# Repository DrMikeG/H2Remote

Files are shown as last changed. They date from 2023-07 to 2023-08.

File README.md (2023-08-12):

# H2Remote

## 12th August 2023 ##

Back to the Tiny

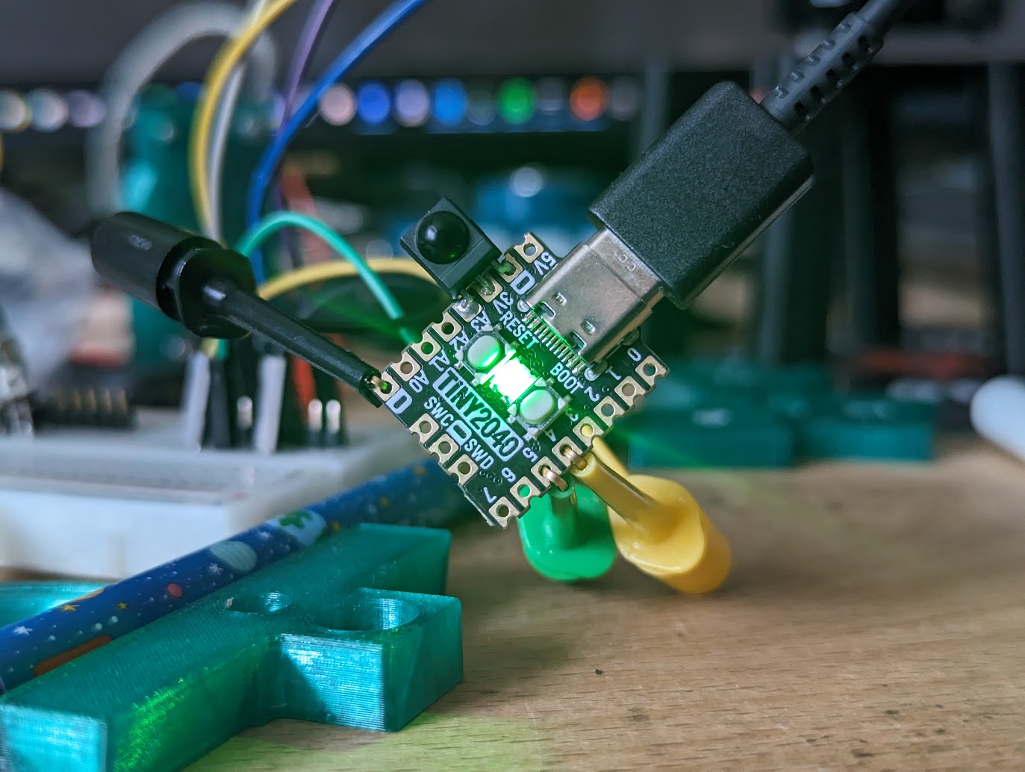
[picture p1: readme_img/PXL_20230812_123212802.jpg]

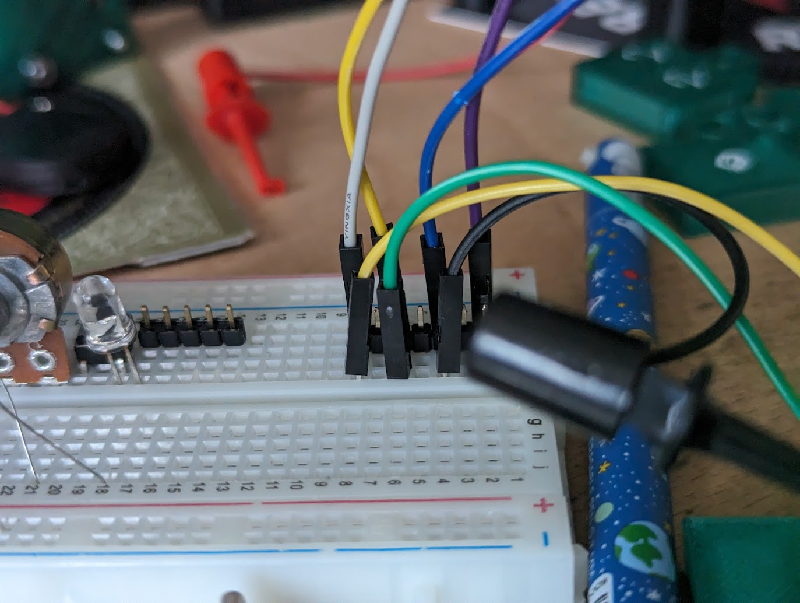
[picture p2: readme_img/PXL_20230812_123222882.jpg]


With minor revisions changing from the NeoPixel to the RGB LED, the code from the feather works on the Tiny.
The hardware UART RX/TX are GP4 and GP5.

blue wire in cable L - GP5 (green clip) connects to the yellow lead, which is L on 2.5mm jack
green wire in cable R - GP4 (yellow clip) connects to the white lead, which is R on 2.5mm jack
copper wire in cable (GND) - GND pin on Tiny
red wire (3v3) cut short

## 5th August 2023 ##

Today I got the feather 2040 flashing its neo pixel.
I also got it to read from the IR receiver.

I tried to decode the remote protocol - thinking it would encode an RGB value - but I'm pretty sure it's just sending an int for each remote key, and the device is mapping the int to a specific color or behaviour.

Looking at the pin order on the feature, it was actually better to swap back to a vs1838b IR receiver, as the pinout is the compatible (although backwards) with 3v3/GND/A0 on the feather.

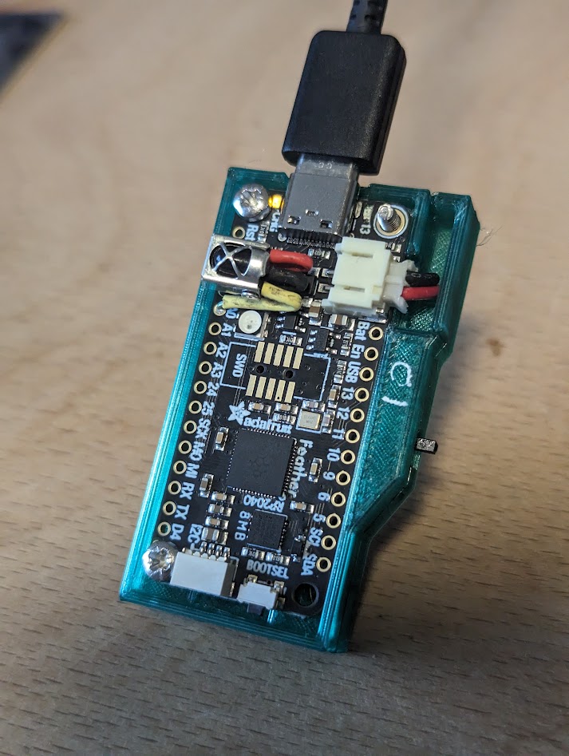
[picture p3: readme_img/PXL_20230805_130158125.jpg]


I also connected the lipo battery (via the switch) which is now being charged (small yellow LED top left)

Next step is to review the TX/RX with the zoom and figure out a common gnd.

On the Pico - I had success with 
``uart2 = busio.UART(board.GP4, board.GP5, baudrate=2400, bits=8, parity=None, stop=1)``





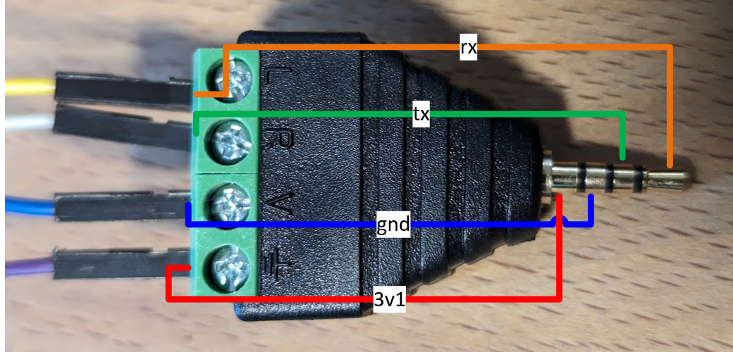
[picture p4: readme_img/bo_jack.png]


UART1 TX and UART1 RX

From the feather documentation:

>>> CircuitPython I2C, SPI and UART
Note that in CircuitPython, there is a board object each for I2C, SPI and UART that use the pins labeled on the Feather. You can use these objects to initialise these peripherals in your code.
```
board.STEMMA_I2C() uses SCL/SDA
board.SPI() uses SCK/MO/MI
board.UART() uses RX/TX
```

```
UART Pins:
UART0 TX: TX, A2, D12
UART0 RX: RX, A3, D13

UART1 TX: D24, MISO, D6
UART1 RX: D25, D9
```

Using the feather I can successfully communicate with the H2 to start and stop recording.
I had 24/25 backwards for a while - and listening seemed to work.

pin 25 is connected to L on the 2.5mm terminal block
pin 24 is connected to R on the 2.5mm terminal block
pin 10 (pseudo gnd) is connected to V on the 2.5mm terminal block

## 4th August 2023 ##

This evening was my first opportunity to start working with the feather 2040

Firstly, I've solvered up some sprung-clip test leads onto some du pont male breadboard leads.

This allows me to make secure connections to the board without soldering on headers.
Very pleased with that idea.

The feature has a very different list of pins available compare to the pico.
I took the 01_pico_IR example and edited it into 08_feather_IR - editing the default pin from GP22 to D6 and editing the pin in use too.
This was the only modification necessary though.

## 31st July 2023 ##

So, I made a boo boo.
The port on the H2 is current limited to 10mA, and despite my previous readings, the tiny 2040 need 25mA to run.
This isn't a surprise as the 2040 chip needs 20mA to idle.

I can't think of a way around this limit, so my board is going to need external power.
I considered some coin cell batteries, and I might go there, but first I want to try a lipo battery.
I went looking for a charging shim with an on/off switch, but realised that most more larger than the tiny 2040, and would present more
mounting problems.

Since I have lost my size advantage, I have ordered a different board to work with, one with native lipo support.
I considered the pimironi version of this, which has an on/off button, but decided I'm going to want the on/off broken out to the side of the case anyway.

https://learn.adafruit.com/adafruit-feather-rp2040-pico/pinouts
https://io.adafruit.com/blog/tip/2016/12/14/feather-power-switch/
https://learn.adafruit.com/adafruit-feather-m0-basic-proto/power-management#enable-pin

## 23rd July 2023 ##
Another thread to pick at:
https://github.com/radicalrendell/zoom_remote/blob/master/zoomctl.py

https://www.webwork.co.uk/2021/03/wireless-remote-control-for-zoom-h2n.html
https://github.com/lowfriars/ZoomRemote

With Zoom connected with trrs breakout, L (yellow wire) on the breakout connects to ping GP4 on a pico.
Code in 04_pico_zoom_rx can receive bits
0x81,0x80

In some of example code for a zoom H4 remote, there is a handshake

```
# handshake
# return true if connected, false if not
def zhandshake(s):
    # send 00, look for 80, then send A1, look for 80 then we are ready
    s.write('\x00')

    zbyte = s.read(1)
    if (zbyte == '\x80'): s.write('\xa1')
        
    zbyte = s.read(1)
    if (zbyte == '\x80'): return(1) 
    return(0)
```

I don't know if sending A1 would do anything for the H2, because we seem to receive an alternating stream of 80,81,80 as it is.

>> Although the recorder supplies 3.3V power, it's not capable of supplying much current, certainly not enough for a wireless link, so regrettably the wireless interface needs its own power source. The communication protocol was clearly designed by an electrical engineer: it consists of key-down and key-up events being sent to the recorder to signal the press and release of buttons on the physical remote control and an encoded status byte being sent to the remote control to illuminate status LEDs (such as recording-in-progress and level indicators). There is an initial handshake to establish the connection of the remote control. 

https://www.webwork.co.uk/2021/05/wireless-remote-control-for-zoom-h2n.html

>>  The control protocol calls for a code to be sent when a button is pressed and a further code when it is released (this allows, for example, auto-repeat on the Volume controls). The codes corresponding to the "press" event for each button are stored in the keySequence dictionary (the release code is the same for all keys).

Data received from the H2n consists of a singled byte which is encoded as follows (red and green refer to VU meter, both on together corresponds to yellow):

Initially, the Zoom device sends a sequence of two bytes: for the H2n these are 0x80 and 0x81, for other devices they may be 
different, but the high bit of 0x80 appears to be intended to signify that it's a two-byte sequence. 

The service sends "key up" messages to the recorder. 

At some point, the recorder recognises the existence of the remote controller and switches to one-byte
responses with the top bit clear. The contents of each byte represents the status of the recorder as follows:
/// 
/// Bit 7   -   1 for handshake phase, 0 once remote control has been acknowledged
/// Bit 6   -   Green status for recorder channel 3
/// Bit 5   -   Green status for recorder channel 1
/// Bit 4   -   Greet status for recorder channel 2
/// Bit 3   -   Red status for recorder channel 3
/// Bit 2   -   Red status for recorder channel 1
/// Bit 1   -   Red status for recorder channel 2
/// Bit 0   -   1 if recording in progress (alternates 0 and 1 when recording paused)

I think the button up code is:
s.write('\x80\x00')

Gradually building up from the various great bits of example code, I've managed to:
- read the h2 RX line
- 'handshake' with the h2 on its TX line
- interpret the post-handshake byte on the h2 RX line
- Send start/stop record in the TX line

This is currently being done with the UART pins, not with PIO.

I need to understand more about PIO if I want to avoid needing to use UART.

I struggled to get two example running at once, so I'm going to try and build a new example with flashing an LED and reading the IR diode.

https://learn.adafruit.com/intro-to-rp2040-pio-with-circuitpython/using-pio-to-blink-a-led-quickly-or-slowly

## 22nd July 2023 ##

Serial 2400 8b no parity 1 stop (8n1)
Bit order: LSB first, inverted logic: no
https://github.com/raspberrypi/pico-examples/blob/master/pio/uart_rx/uart_rx.pio

"With no activity on the recorder the RX and TX pins show ~2.7 volts"

"When you press the record button on the remote, after a moment the recording LED lights up"

"On the oscilloscope I can see three different square wave patterns for the three different buttons on the TX pin and a single type of square wave
on RX to light the LED."

"The following images show the signal for the record button then that sent in
response to to light the LED.

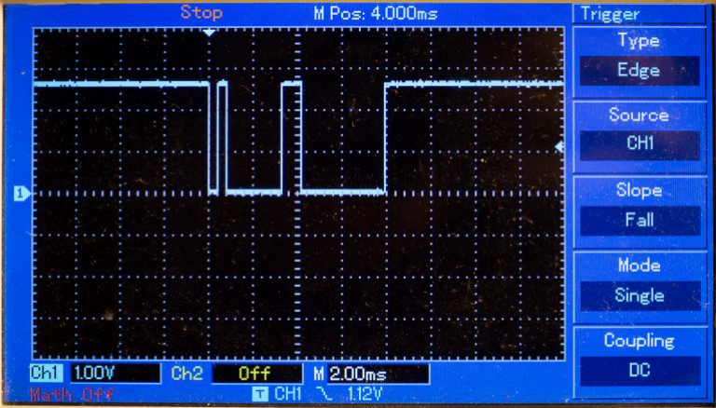
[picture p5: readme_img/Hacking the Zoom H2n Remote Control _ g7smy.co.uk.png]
Signal sent by the remote when Record pressed
 Signal sent by the remote when Record pressed

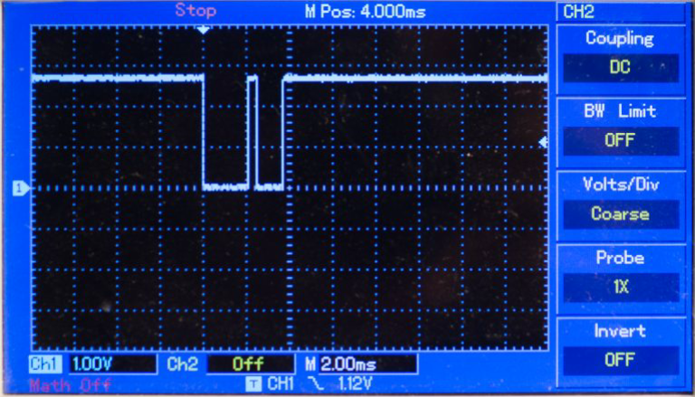
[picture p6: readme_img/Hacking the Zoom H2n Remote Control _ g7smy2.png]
Signal sent by the Zoom recorder to light the LED in the remote
 Signal sent by the Zoom recorder to light the LED in the remote

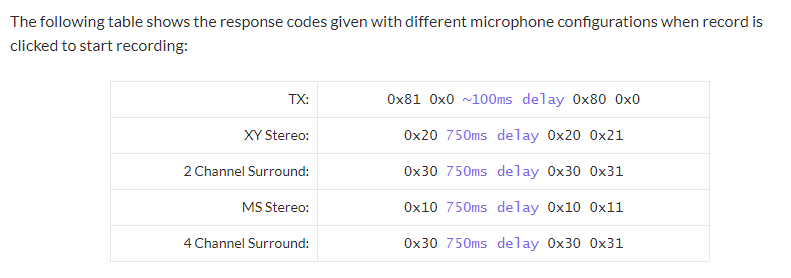
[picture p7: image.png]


Can I get the first byte of the response? 0x20

Using teensy example code:
```
// incoming data
Serial2.begin(2400, SERIAL_8N1);  // Remote Receive - RX
Serial3.begin(2400, SERIAL_8N1);  // Remote Transmit - TX
```

https://arduino-pico.readthedocs.io/en/latest/piouart.html

```
Equivalent to the Arduino SoftwareSerial library, an emulated UART using one or two PIO state machines is included in the Arduino-Pico core. This allows for up to 4 bidirectional or up to 8 unidirectional serial ports to be run from the RP2040 without requiring additional CPU resources.

Instantiate a SerialPIO(txpin, rxpin, fifosize) object in your sketch and then use it the same as any other serial port. Even, odd, and no parity modes are supported, as well as data sizes from 5- to 8-bits. Fifosize, if not specified, defaults to 32 bytes.
```

https://learn.adafruit.com/intro-to-rp2040-pio-with-circuitpython?view=all

## 21st July 2023 ##

My TSOP2238 IR diodes arrived today.
These have a different leg ordering to the standard pins I use.

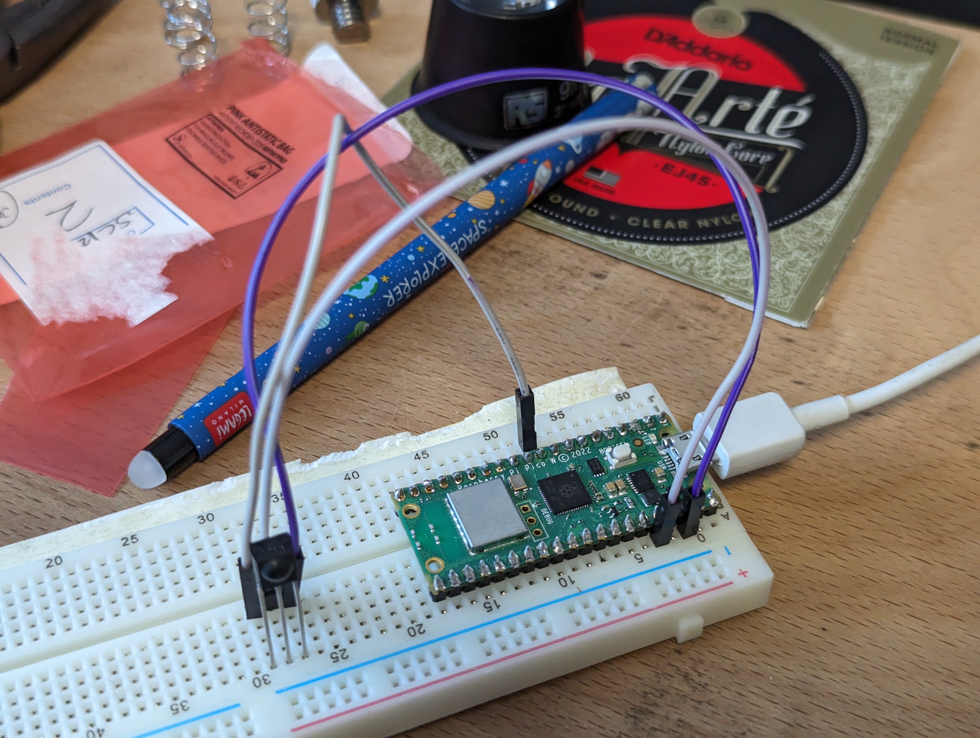
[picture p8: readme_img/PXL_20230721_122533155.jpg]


Pin 1 (left when facing) - purple wire to GND
Pin 2 - white wire to 3v3
Pin 3 grey wire to GP07 (working with test script 01_pico_IR_PIO)

This works great, so I can plan to solder it on to the Tiny_2040

## 18th July 2023 ##

Serial 2400 8b no parity 1 stop (8n1)
Bit order: LSB first, inverted logic: no
https://github.com/raspberrypi/pico-examples/blob/master/pio/uart_rx/uart_rx.pio

// bytes to start and stop the recorder, a negative number is used as a delay
int record[5] = { 0x81, 0x0, -100, 0x80, 0x0 };  

# 17th July 2023 ##

Tiny 2040 from Pimoroni is compatible with firmware designed for the Raspberry Pi Pico.

It is one-third of the size of a Raspberry Pi Pico & has 16 GPIO pins while Raspberry Pi Pico has 40 pins.

With proper orientations & mapping of the pins, there is no loss of functionality despite lesser pins.

Board has some unique features that Raspberry Pi Pico does not have, such as a dedicated reset button, a fourth ADC pin, RGB LED & USB C port.

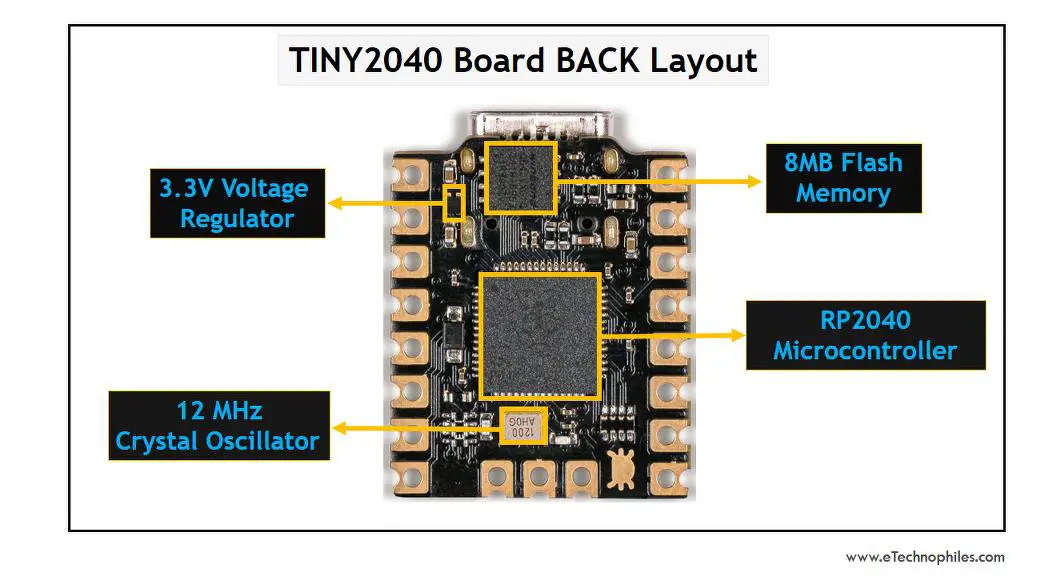
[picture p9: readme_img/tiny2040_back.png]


Pin numbers 
Pin numbers are available on top of the board. 
These are numbered as logically &, these relate to GPIO pin number as per the Pico pinout reference.

Tiny 2040 Pinout
Pinout of the Tiny 2040 shows that it has a total of 16 pins(3 additional pins are for debugging) out of which 12 are I/O pins: 8 digital, 4 analog(12 bit).

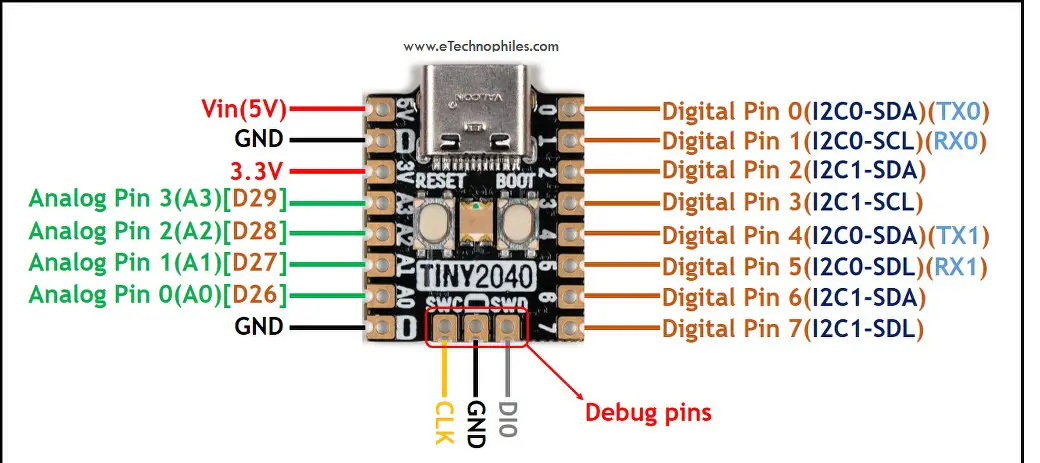
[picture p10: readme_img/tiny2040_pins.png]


The remaining pins are 2X Ground, 1X 5V, and 1X 3.3V. Board supports 2X UART(UART0 and UART1), 1X SPI, and 2X I2C(I2C0 and I2C1) interfaces.

I have been using GP22 (pin 12) on the pico.

I can try and use D0
Or I could try to use D26 (A0) in the tiny, which would be 

I programmed up the Tiny 2048 with the code in 01_pico_IR.
It didn't work because the Tiny doesn't have board.GP22 defined.

I made a copy of the code in 03_tiny2034, including the libraries, and changed the default pin to 7.

It was a bit iffy holding the wires on, but I got the tiny to recognize codes.

Perfect!

IR - Infrared Receiver (TSOP38238)
To use, connect pin 3 (all the way to the right) to 5V power, pin 2 (middle) to ground and listen on pin 1. It doesn't do any decoding of the signal, just passes the 'raw data' along.

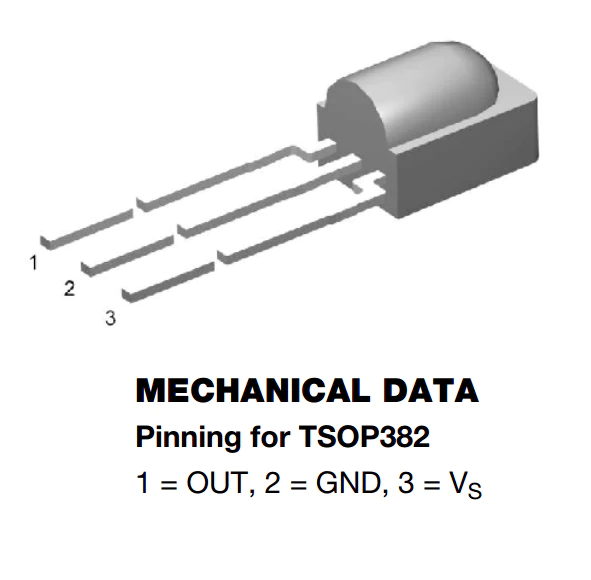
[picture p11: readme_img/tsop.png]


I was puzzling this evening about the layout of my board. Because the gnd pin is in the middle, there was no neat way to pop the part into three adjacent pins on the tiny.

I couldn't figure out why the internet didn't have 100s of tips about how to swap the order of legs, how to bend them around, or shim boards that let you change the order.
I even considered making one.

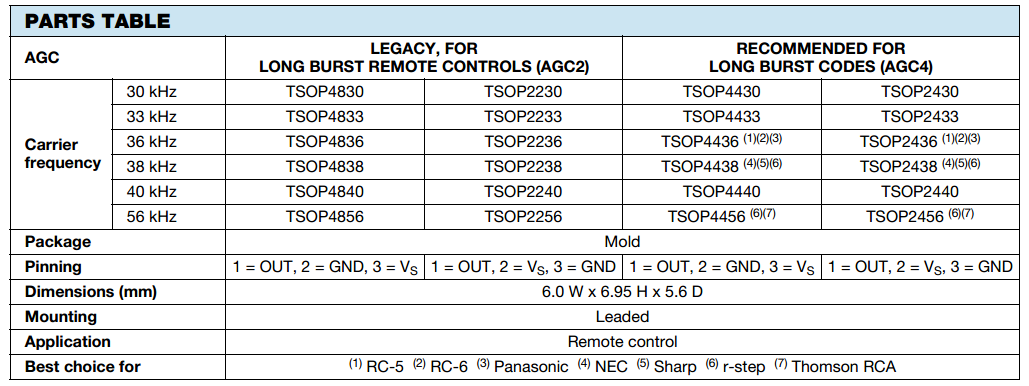
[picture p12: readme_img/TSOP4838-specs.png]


Then I learned this - and it's a bit of a revelation.
The TSOP4838 is the same part as the TSOP2238 - except they have different pinning!

I can get OUT,VS,GND - which backwards is GND/VS/OUT - which is the order of the pins I want to use.

## 16th July 2023 ## 

Started work on a shock-mount for the H2.
This will also give me a frame on which to mount the remote?

Time to start on the remote. Some parts have arrived - 2.5mm jacks. TRRS.

Pin one being the tip of the 2.5mm jack plug:
1. Remote Receive – RX
2. Remote Transmit – TX
3. Ground
4. 3.1V – Power



VBUS
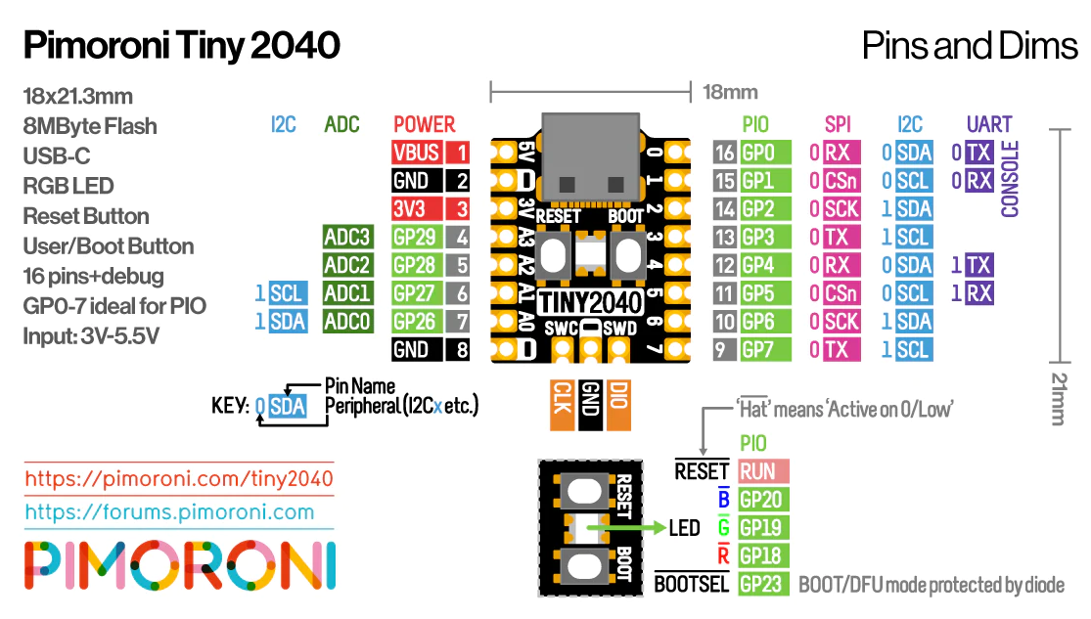
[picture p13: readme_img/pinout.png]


Pico PIO IR decoding:
https://github.com/rdear4/Pico_PIO_IR_Receiver

Let's start for something basic with the IR reading.
https://learn.adafruit.com/ir-sensor/using-an-ir-sensor

Connected up a KY-022 Infrared sensor module to pico WH

Gnd, 3v3 and GP1 (pin 2)

Adafruit CircuitPython IRRemote library on your CircuitPython board.

Flashed on on adafruit-circuitpython-raspberry_pi_pico-en_US-7.3.3.uf2

Copied on lib adafruit_irremote.mpy

Using the code in 00_pico_IR_test, I could identify an IR pulse using my samsung TV remote.
Sensor seems happy running at 3v3

Setup rdear4's pio library. Added adafruit_pioasm.mpy.
Changed module input to pin gp22 (pin 29)

It can read volume codes from my remote.
11100000111000001110000000011111
11100000111000001110000000011111
11100000111000001101000000101111

It can register, but not recognise my Nikon remote.

It can recognise and understand my Edifer remote.
It can recognise and understand my son's cheap LED light remote.

Now I need to write my own PIO programs based on this to detect signals from the H2?

### Tiny 20240 ###
Getting started...
https://www.instructables.com/Introducing-the-Tiny-2040-Microcontroller-IR-Commu/
This even shows a receive IR example!

Plugged in to USB C. Powered, but did not detect. Changed cable. Appeared are rp2.

There is different firmware for the 2mb and 8mb versions! I have the 8mb version.

Copied on adafruit-circuitpython-pimoroni_tiny2040-en_GB-7.3.3.uf2 (not latest, but I used 7.3.3 on picos)

## 14th July 2023 ##

timelapse/timelapse/timelapse

https://www.tomshardware.com/how-to/use-raspberry-pi-camera-with-bullseye

```The latest Raspberry Pi OS is based upon Debian 11 (Bullseye) and with this new release we see the familiar raspistill and raspicam camera commands replaced with a new suite of open source tools dedicated to getting the most from all of the official Raspberry Pi cameras.

Libcamera is a support library for Linux, Android and ChromeOS which was introduced to the Raspberry Pi via a previous Raspberry Pi OS, but it has come into the spotlight due to the changes made for Bullseye. The app offers an easy to use series of tools which can tweak many different camera settings (aperture, color balance, exposure) via a series of switches issued when the command is invoked.``````

Done some very cool things with a raspberry pi 3.
Remote development, touch screen. camera. 3D printed supports.
Setup for time lapse - I think.

## 10th July 2023 ##

Resurrecting a gemma board to run circuit python.

Not sure if my gemma is an M0

https://learn.adafruit.com/adafruit-gemma-m0/circuitpython

Plugged in and turned on.

Double pressed reset. Waiting and button went green.

I studied a project a while ago about reading IR code using PIO.
https://github.com/raspberrypi/pico-examples/tree/master/pio/ir_nec

I didn't use it at the time, but it might be a great starting point for the H2 code generation.

https://github.com/carolinedunn/timelapse/blob/master/README.md

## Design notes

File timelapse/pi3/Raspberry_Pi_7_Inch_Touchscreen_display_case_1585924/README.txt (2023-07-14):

Raspberry Pi 7 Inch Touchscreen display case by luc_e on Thingiverse: https://www.thingiverse.com/thing:1585924

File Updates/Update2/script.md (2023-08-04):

Let's recap what I am doing.

I have this mid-range zoom h2 microphone.

[ b roll video of microphone ]

I use it for recording some solo pieces, but really I bought it for recording at the community and school orchestras I help at.

It has an microphone array, which is good for capturing ambient sounds, like a full orchestra - but the best place to position it is generally right at the front of the audience, or with the conductor.
As such - it's not very convenient to start and stop recording. I can't really walk out from the string section between songs to physically press the button.

In the past, I've generally just pressed record before the concert starts, paused it for the interval and stopped it at after the concert has finished. But that's pretty annoying too.

I could ask the conductor to do it - but generally they have other things on their mind - like greeting conducting the orchestra.

What it needs is a remote control - and in fact is has a 2.5mm jack port on the side for a remote control. It's a four wire interface, for serial communication with a protocol - so not just an sp/sf switch.



And this is the official remote control. It has a big red button, to start/stop recording and shows a red LED when recording and a flashing LED when the recording is paused.

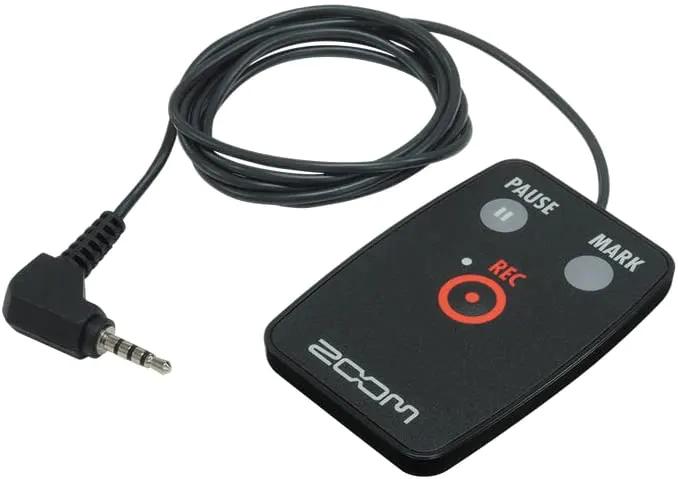
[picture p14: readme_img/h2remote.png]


But for some maddening reason the stock remote control is wired! 

So I'd need to trail meters of cables between the orchestra and the conductor's stand for that to be any use.

I was a bit surprised there wasn't a wireless remote available - but I found a few other enterprising hackers online who had set out on similar paths. Including resources for reverse-engineering the serial protocol of the remote.

Let's talk about my initial plan - and then my current plan.

My initial plan was for a parasitic wireless transceiver.

I wanted this tiny 2040 micro controller



With a tsop IR reciever

 to listen for button presses from an IR remote control.

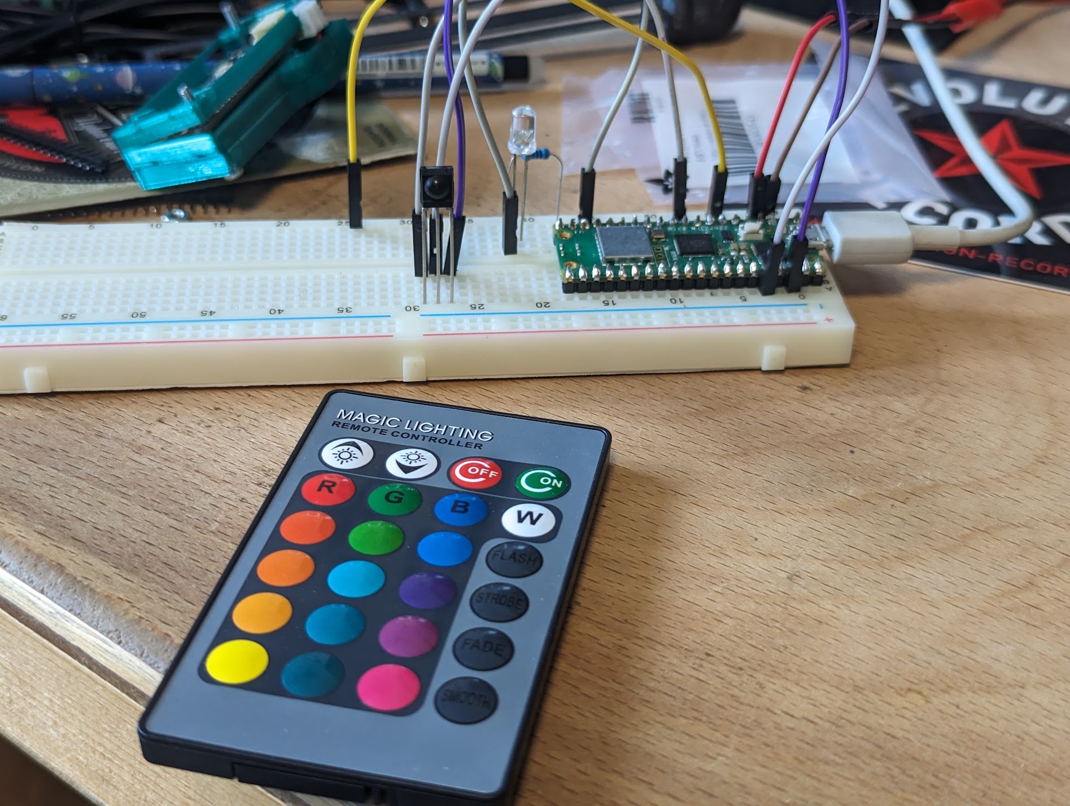
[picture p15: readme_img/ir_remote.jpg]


And the Tiny 2040 would be wired to a 2.5mm jack, and able to plug-in to, communicate with and control recording on the H2.

In this approach, the IR remote would have its coin cell battery, the but Tiny 2040 based transceiver would be powered from the 3 volts available on the 2.5mm jack - ultimately powered from the 2x AA batteries in the H2.

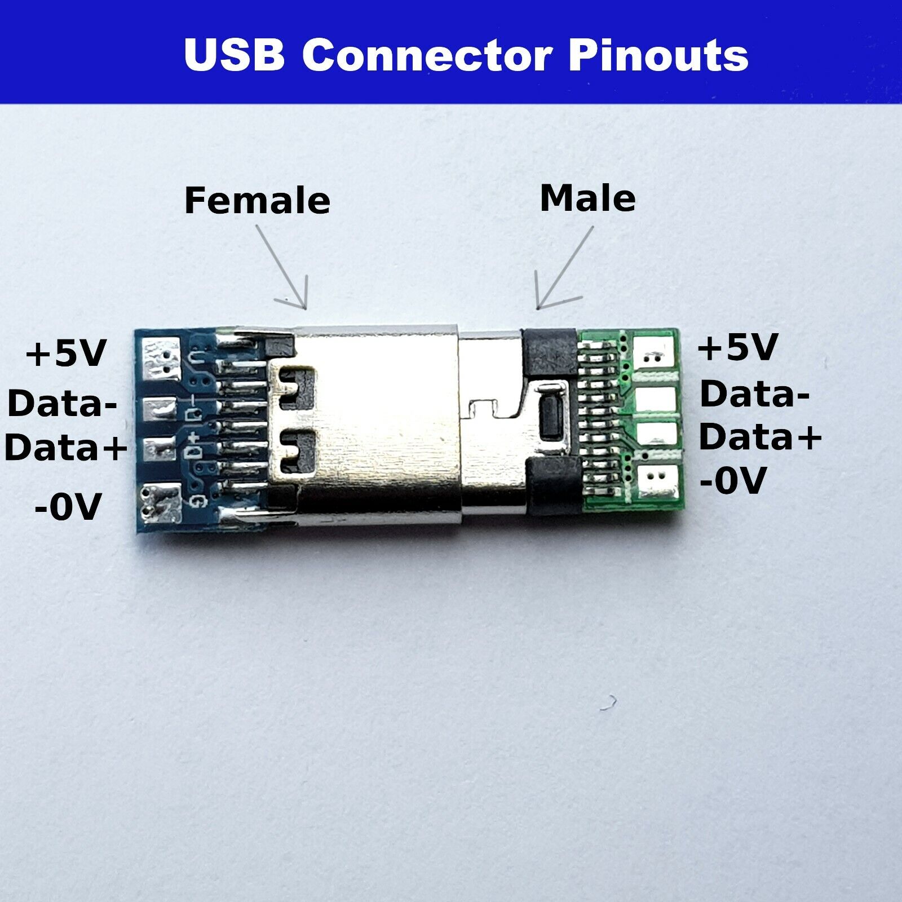
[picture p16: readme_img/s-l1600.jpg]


The tiny 2024 doesn't have mounting holes - but the USB C connector doesn't need to be used when its in operation, so I plan to use a Male breakout to form a mechanical connection between the board and a 3d printed housing.

Now, if you've seen my previous video - you'll have seen me doing an experiment to find out what the current draw was for the tiny 2040, to check I could power it.

Anyway - turns out I made a mistake.

DSC_4575.MOV
When I press the tac button, tiny 2040 is drawing power from the 2AA batteries, with the multi-meter in series.
Doing this, the Tiny 2040 draw 25mA - which makes sense because when I look at the data sheet for the RP2040 chip - that idles as 20mA.

Importantly, this is an order of magnitude off from the measurements I took before.

I wasn't previously worried about the power supply - but now it warrants further analysis.

DSC_4574.MOV
Circuit which shows current draw.
H2 is providing power now from 2.5mm jack.
Tac switch is pressed to complete circuit. 
LED is powered, with a B5k potentiometer providing variable current limiting.
The multi-meter is in series to show the current in the circuit.

As I dial down the resistance provided by the potentiometer, the LED glows slightly brighter.

DSC_4576.MOV
Very short showing that max current draw (zero resistance) cannot draw more than 10mA from the H2.

So - I cannot power an RP2040 chip from the limited current coming out of the H2.

I can't build a parasitically powered device - so now I need a plan that involves a powered transceiver, batteries and on-off switches.

There is plenty of power in the H2 - but it's the current limit on the remote port that's the problem.

The 2 AA batteries have up to 4800 mA hours.

The capacity of a CR2032 coin cell battery is typically around 225mAh
This would run the tiny for about 10 hours.

And then there are small rechargeable li-po batteries which typically have 150mAh - 500mAh depending on size.
This would run the tiny for about between 6 20 hours.

I pondered this for a couple of days, undecided between two approaches.

So I'm going to try them both.

I'd prefer to use a lipo rechargeable battery. But to do that I need to make some concessions on size.
Even small lipos are quite big - at least compared to the tiny. The smallest I have in stock is a 150mAh, which is still bigger than the tiny.
Plus since its rechargable, I will also need to add a way to charge it.
Using an external lipo charger really means having a JST socket to connect/disconnect the battery from the tiny
And since it's power is no longer controlled by the H2, I will also need to add an on-off switch.
Because the Tiny is so bare-bones, it doesn't have a JST socket, battery charging support, or an enable pin. I can add these from a lipo shim, but the shim is as big as the tiny.

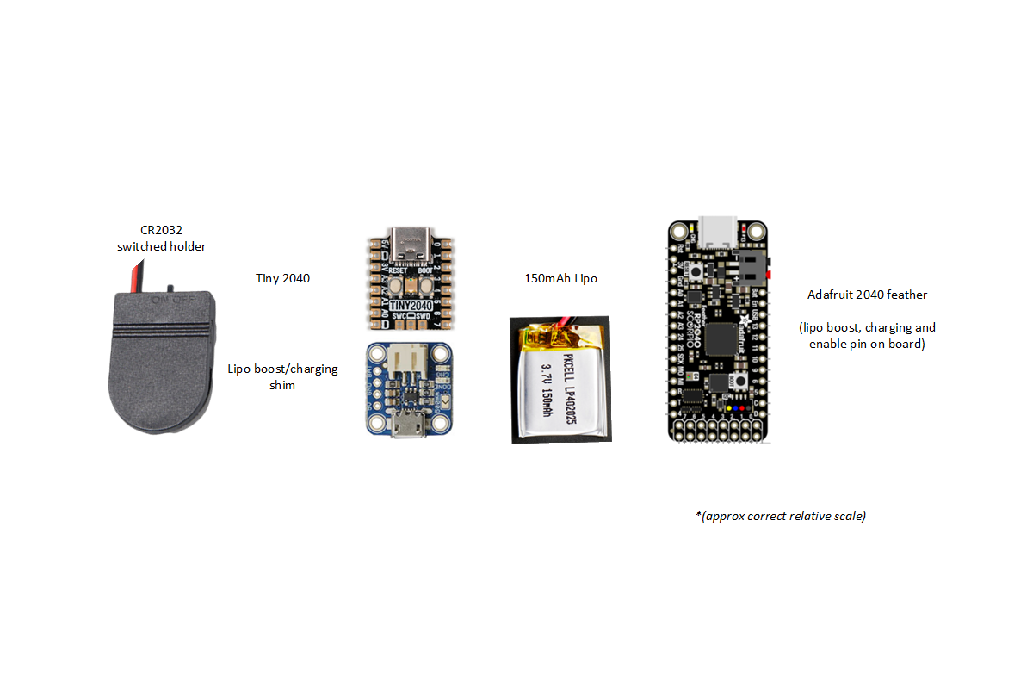
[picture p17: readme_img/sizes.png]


A more sensible option here might be to move away from the tiny 2040, and to use something like an adafruit 2040 feather. Although it has a bigger footprint, the lipo charging, management and on/off are all supported on board - I just need to break out the USB C port for charging - which is pretty convenient.
As you can see from the picture, where things are approximately to scale, the feather on the right is certainly larger than the tiny and the shim together.

Video of measurment of current draw for the feature.

Checking the current draw for the feather, it has very similar 26mAh draw - still needs its own power, but will run for just as long as the tiny on the lipo battery.

So that is one option I am building out.

Another option that might allow me to stick to tiny is to use a disposable coin cell battery.
A CR2023 in an enclose with a switch is a similar size to the lipo, but could used directly with the tiny 2040. I wouldn't need to add a recharging port or another on/off switch.

Plus it should run to 10 hours of a single coin cell.

I think this is also a good option, so I'm going to prototype this too.

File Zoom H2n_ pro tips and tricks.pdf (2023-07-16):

Home (https://www.codejam.info/) | About (https://www.codejam.info/val.html) | Photography (https://photography.codejam.info/) | 🌞

The Zoom H2n (https://amzn.to/3GwRCAL) is an awesome portable microphone with a long battery life. It’s very versatile and delivers a solid sound.

# Zoom H2n: pro tips and tricks

Everything I wish I knew when I got my H2n
September 24, 2021

In this post, I’ll give you all of the tips and tricks that I discovered over the years using my H2n, that made me more efficient at using it and allowed me to do even more with it.

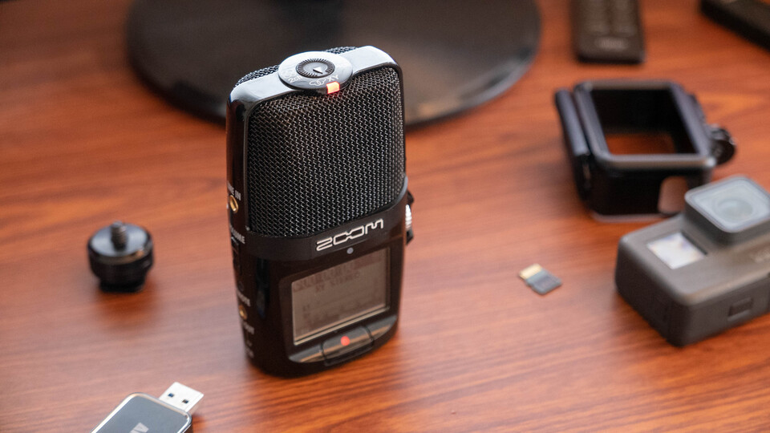
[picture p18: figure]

But first, I’ll give you a little bit of backstory about how I got there in the first place. Feel free to skip it.

## The story about my H2n

The reason I got it in the first place was put it in my motorcycle jacket while I ride to record clean engine sound for my GoPro recordings. (https://www.youtube.com/playlist?list=PL3gQ6-WYh7kU8QjpRSMpDknhAwvccFiMu) This is how Royal Jordanian, (https://www.youtube.com/c/royaljordanianR) a famous motorcycle YouTuber, uses his H2n, and his results are remarkable.

I used to have a Zoom H4n (https://amzn.to/3DR0D68) because I liked that it could act as an external sound card where I could plug XLR microphones and jack instruments as well, but it was too big to fit in my motorcycle jacket, which turned out to be what allowed me to get the best sounding audio on a motorcycle.

Anyways, because I had that mic around when I started making more YouTube videos, (https://www.youtube.com/FunkyVal) it became my main device to record voice in various settings (indoors, outdoors, multiple people interviews, live streaming). I also use it to record acoustic instruments.

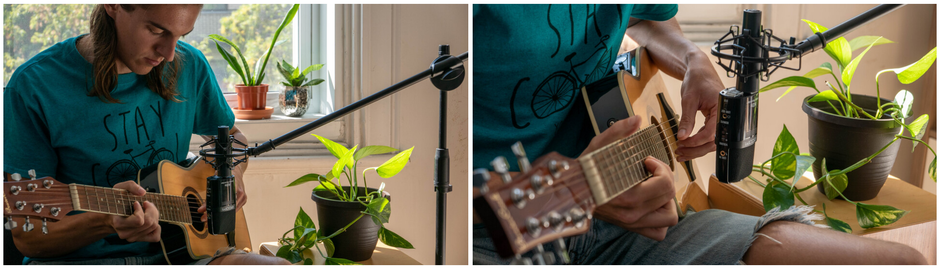
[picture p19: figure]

While specialized microphones might give you even better results in specific situations, the H2n has allowed me to record high quality audio in an impressively wide set of settings.

After years of using it, I have a couple of tips to share with you that will make you even more productive with your H2n and enable you to do even more with it.

## My go-to mic setting

The H2n has 5 built-in microphones and lets you use them in the following settings: (https://composerfocus.com/zoom-h2n-review/)

X-Y stereo: (https://en.wikipedia.org/wiki/Stereophonic_sound#X-Y_technique:_intensity_stereophony) 2 mics in the front.

M/S mid/side: (https://en.wikipedia.org/wiki/Stereophonic_sound#M/S_technique:_mid/side_stereophony) 1 mic in the back, 2 mics on the sides with adjustable recording width. 2-channel surround: X-Y and M/S converted to 1 stereo track.
4-channel surround: X-Y and M/S converted to 2 stereo tracks.

I personally use X-Y stereo the vast majority of the time. If you don’t know which one to chose, I would default to this one.

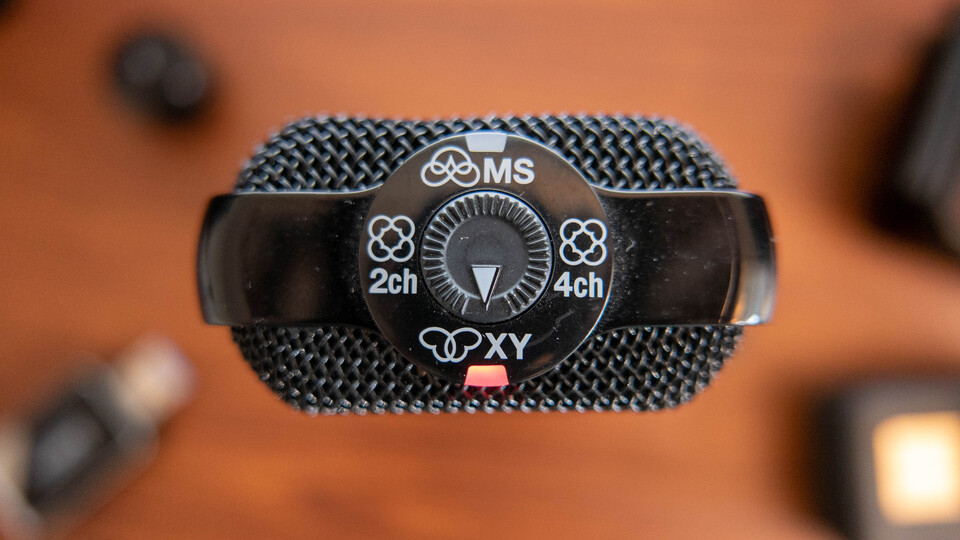
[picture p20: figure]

It’s going to record from the front of the Zoom (where the screen is), which is convenient because you’re facing the front of the mic when you’re recording. This allows you to easily monitor the levels on the screen, and puts the record button right in front of you.

That being said the H2n is well designed because the clipping light on top is visible from both sides, meaning that if you want to record in M/S mode, you’ll still see the light while facing the back of the Zoom!

## My go-to gain setting

When I first got my H2n, I wasn’t sure where to put the gain. My usual rule of thumb with gain is to put it as high as possible at the source so that the highest peaks I plan to have are gonna be close to 0 dB, but won’t clip.

Most of the time, I mount the Zoom on top of my camera, or I put it on a surface about an arm’s length in front of me. In those conditions, I found that leaving the gain on 8 all the time gave me the best results. It’s perfect to record my voice clearly and any meaningful context sound, without clipping, and leaving enough headroom for any reasonable surprise peaks.

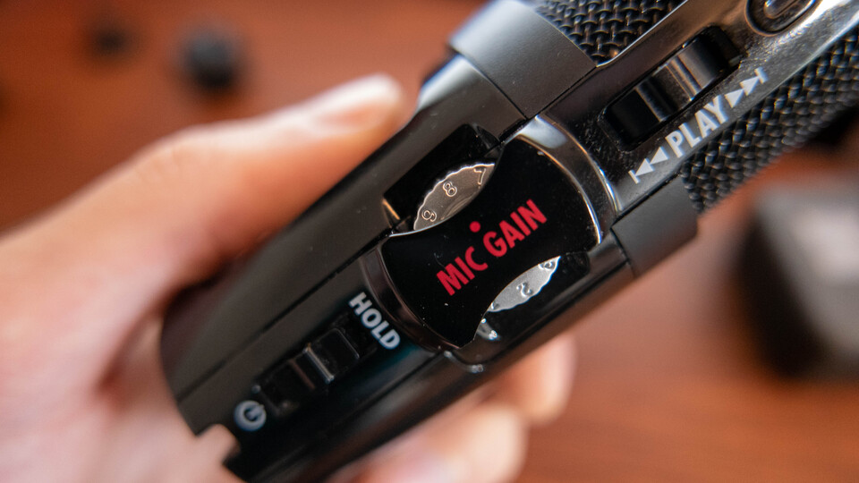
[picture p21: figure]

Because it stays there most of the time, I ensure that all the recordings that are made in similar conditions will have consistent levels, so that I don’t have to adjust them one by one in post. I just boost the gain a bit more at the track level, and add some compression to avoid unnecessary peaking.

So I always leave my Zoom with a gain of 8 by default, and if I’m in a recording setting that differs from my usual use case, like singing very close to the mic through a pop filter or recording an instrument, I’ll go back to step one where I try to get the gain as high as possible while making sure it doesn’t clip during the highest peaks I plan to have. FWIW in those settings, I rarely needed to go below 6.

## Battery and clock reset trick

You might have noticed that the H2n internal clock is reset when you remove the AA batteries to change or recharge them. It’s pretty frustrating to have to configure the date and time again every time you recharge the Zoom!

But there’s a neat trick that I’ve found on Reddit. (https://www.reddit.com/r/livesound/comments/ci181c/comment/evc0nt0/) If you change the batteries one at a time, e.g. without ever having no battery in the Zoom at all, it will keep the clock intact!

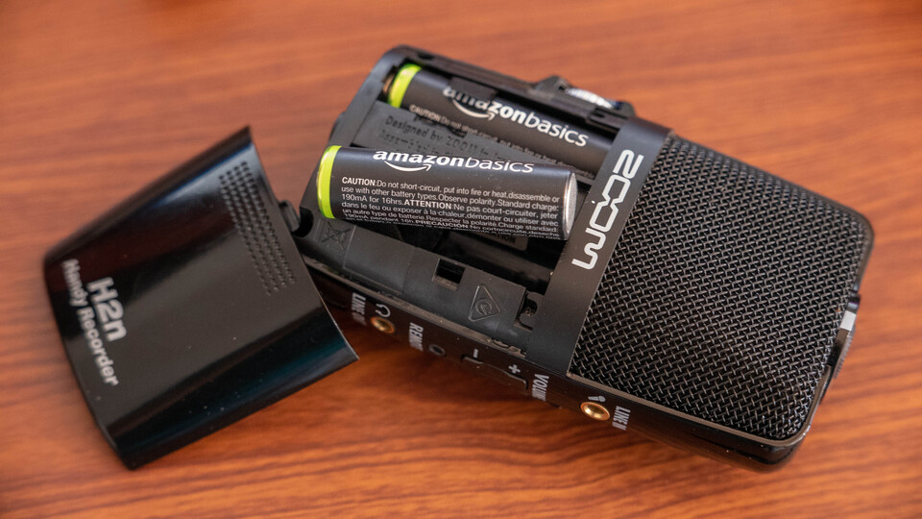
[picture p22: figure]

## Preventing the filename counter to reset

By default, the H2n names files like ZOOM0001.WAV , incrementing the number for every new file.

This is fine with me, but every time I empty the SD card, the file resets to ZOOM0001.WAV ! There’s no persistent internal counter like with my camera.

This is annoying because I end up with conflicting filenames, and I can’t uniquely identify a specific Zoom recording by its name. Not great.

If you want to keep incrementing the number after wiping your SD card clean, just leave the latest file you recorded there! For example if you recorded all the way to ZOOM0363.WAV , just leave that file there, and the next one to be recorded will be called ZOOM0364.WAV .

If even this single file is large enough that you want to remove it as well, you can drop an empty file instead with the same filename, and that’ll do the trick. 👌

But beware, if you ever reach ZOOM9999.WAV , the H2n will not let you record any further and will just error with DATA FULL , even if there’s still technically enough free space on the SD card.

For this reason, and also because it’s even easier overall, I recommend switching to naming files after the date, which is something that I didn’t know was possible until very recently!

## Using date and time as filename

If you want something more deterministic to name files that the default strategy of incrementing a counter that resets every time you empty the SD card, I recommend switching to using the date file naming strategy instead.

You’ll find it from the MENU button on the right, in REC , FILE NAME , and set it to DATE there.

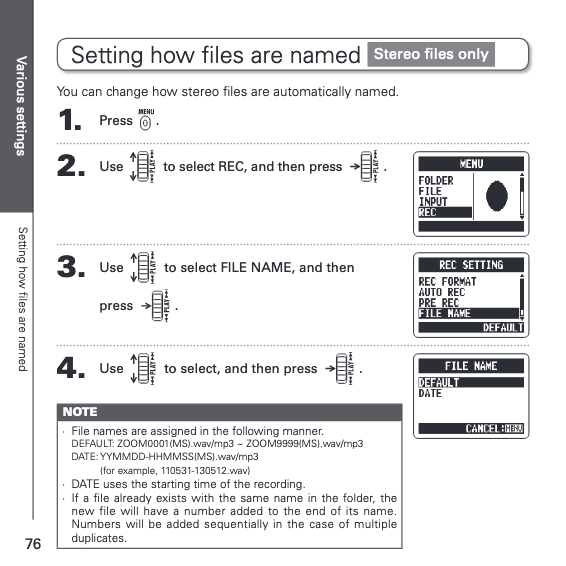
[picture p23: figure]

From the operation manual

## Hot shoe mount

Because I often record YouTube videos, (https://www.youtube.com/FunkyVal) I like to mount my H2n on top of my camera to get high quality audio in my videos.

I know most YouTubers use the Rode VideoMicPro (https://amzn.to/3dL7cMA) or one of its declinations, but since I already had the H2n, I didn’t want to bother buying a new mic for video.

It turns out the H2n can easily be mounted on top of a camera as well, with the help of a cheap hot shoe adapter! (https://amzn.to/3EMi6xK)

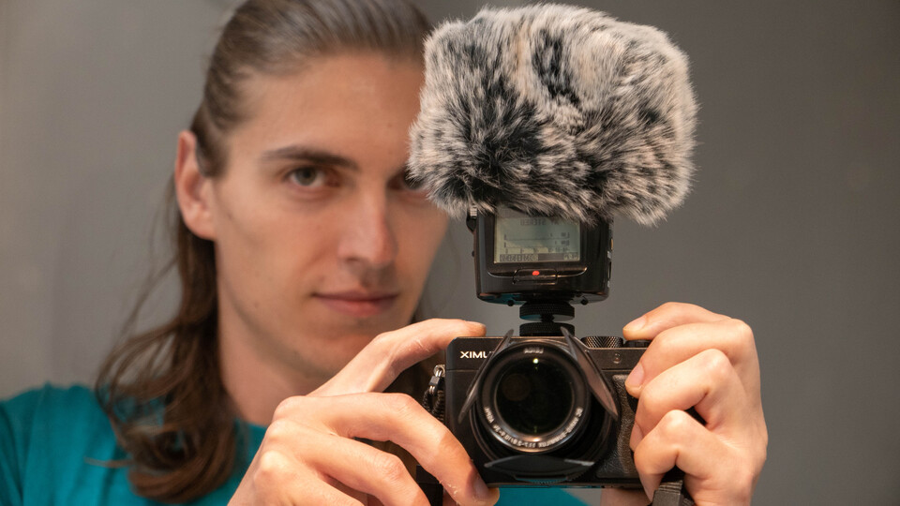
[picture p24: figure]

Note: in that setup, I noticed that the H2n picked up noise from my camera strap rubbing and bouncing on the camera body and tripod when moving around, e.g. when vlogging.

To avoid that, make sure to remove the camera strap before you record, if you usually have one attached!

On my camera it’s a bit annoying to do, but definitely worth it to have a clean sound. I’m looking forward to buying the Leash by Peak Design, (https://amzn.to/31SMN5z) even though it’s a bit more expensive than what I’d like to pay for a camera strap, it’s super simple to attach and detach and that would make my life much easier.

Edit: I ended up buying a simple (and much cheaper) quick release connector (https://amzn.to/3GBVUqn) from Amazon which does wonders with the original strap from my camera.

## Wind muff

A wind muff is a must for outdoor recording especially if it’s a bit windy. This is the one I use, (https://amzn.to/3yeiwdE) it’s for the H4n but works perfectly on the H2n as well!

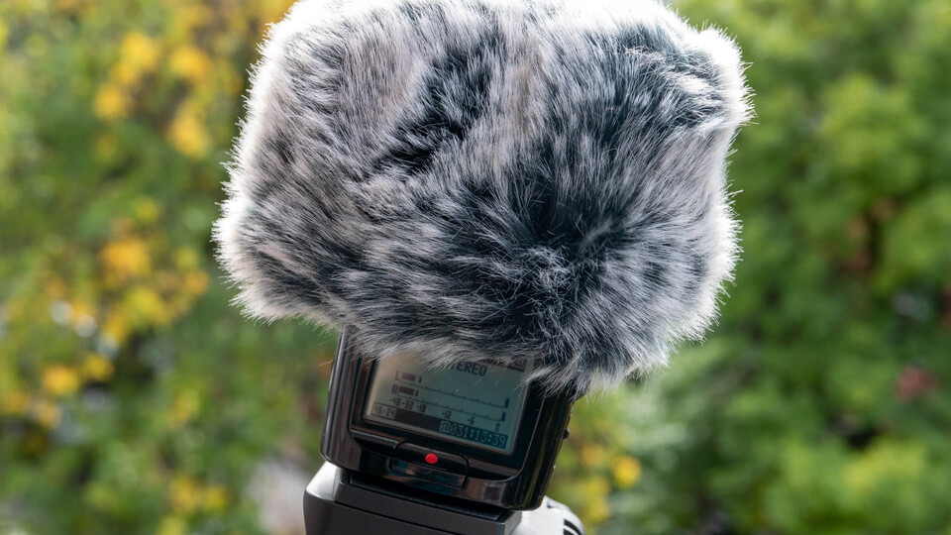
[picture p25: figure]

Note: if like me you’re confused between the “H4n Fur” and “H4n Pro Fur” variations and don’t know which one to pick, keep in mind that it’s “H4n” and “H4n Pro” furs, not a “Pro Fur™”. 😂

Zoom also provides one as part of their H2n accessory pack, (https://amzn.to/3dIhtcs) and if you’re going to buy a few of the items that are part of it, it might be cheaper to just get the pack!

## Mic stand adapter

Another thing that’s part of the accessory pack (https://amzn.to/3dIhtcs) that I didn’t get but probably should have, is the mic stand adapter. (https://amzn.to/31MZzmD)

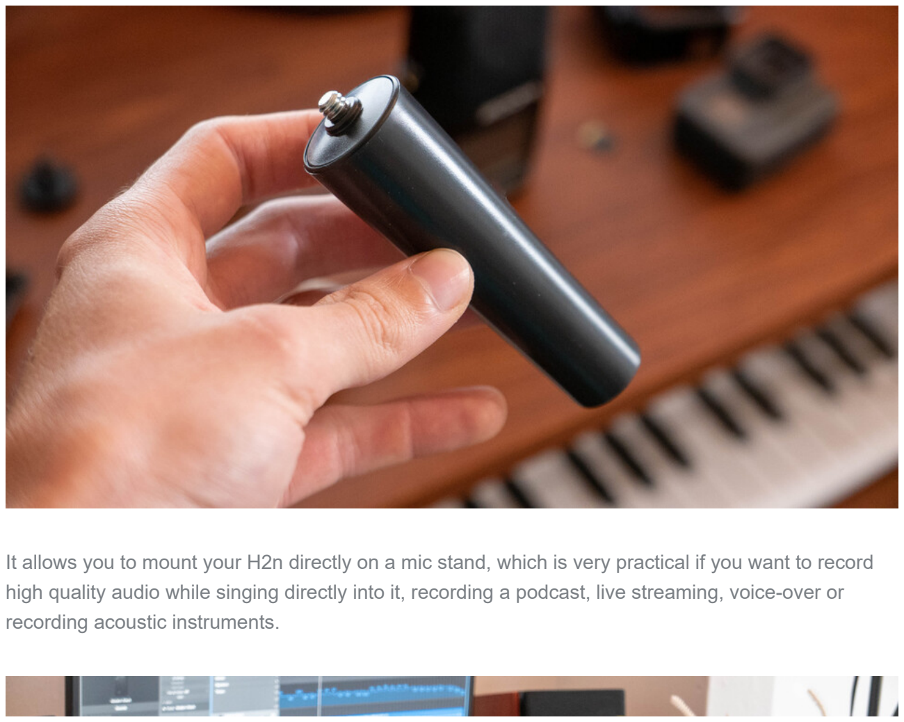
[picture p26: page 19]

It allows you to mount your H2n directly on a mic stand, which is very practical if you want to record high quality audio while singing directly into it, recording a podcast, live streaming, voice-over or recording acoustic instruments.

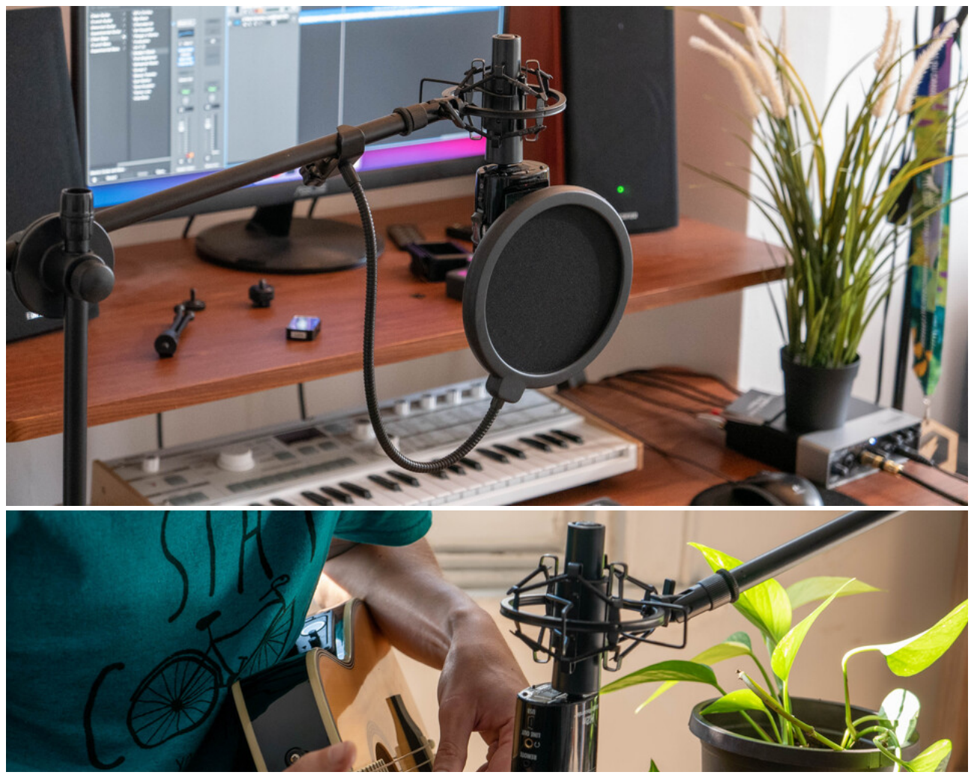
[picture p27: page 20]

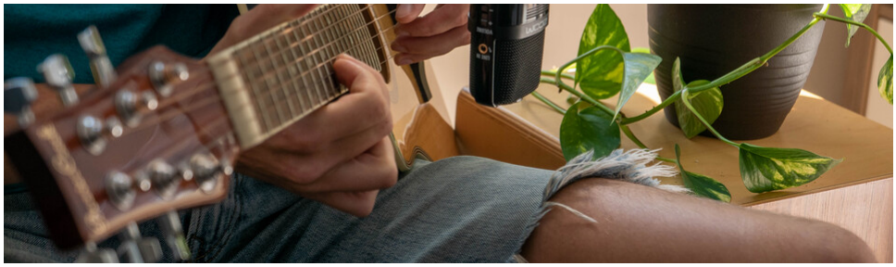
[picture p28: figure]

This is the stack that I personally use for this kind of work and I’m super happy with it:

Mic stand, (https://amzn.to/31QFlbt) this one is a bit on the cheap side but gets the job done. You can even put two mics on it!
Shock mount, (https://amzn.to/3ES5KUY) key element to avoid noise in the recording from vibrations around the mic. This one specifically is compatible with the H2n mic stand adapter. (https://amzn.to/31MZzmD) Double-check the diameter if you get another one.
Pop filter, (https://amzn.to/3GygpV1) to remove artifacts or distortion from pronouncing letters like P, T, K and S very close to the mic.
And obviously the mic stand adapter (https://amzn.to/31MZzmD) to mount the Zoom on the whole thing.

Here’s an awesome article on why a shock mount and pop filter are important (https://www.lewitt-audio.com/blog/do-i-need-a-shock-mount-and-a-pop-filter-for-my-microphone) if you’re not sure if you need them or not.

## Use as an audio interface

If you have the proper cable, you can connect your H2n to your computer via USB and use it as an audio interface, meaning that you can capture sound from it directly from a screen recording or from your DAW!

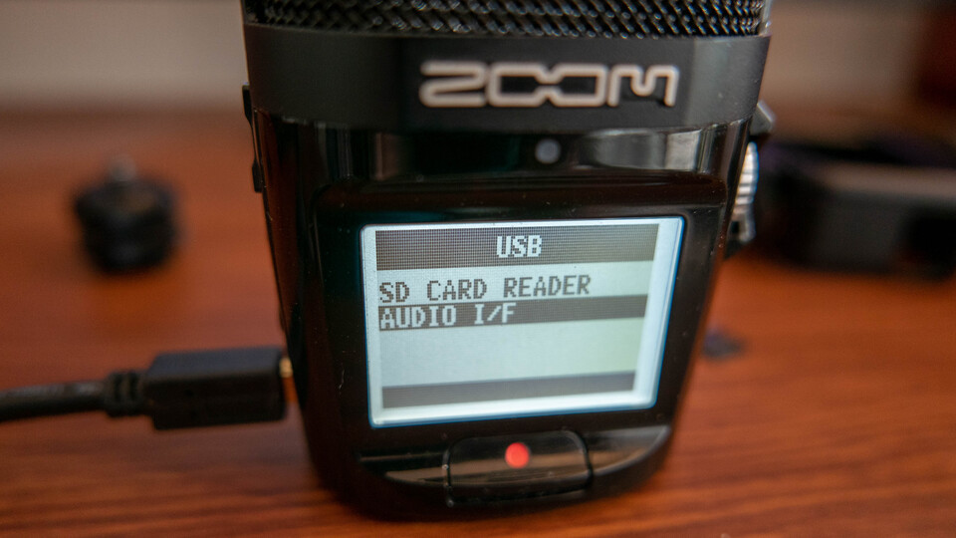
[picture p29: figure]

They don’t seem to mention it anywhere though but keep in mind that you specifically need a Mini-B USB connector on the H2n side (which is not that common).

Again, this is the cable I use, (https://amzn.to/30gb2KN) but if like me you’re gonna need so many accessories that turn out to be part of the H2n accessory pack, (https://amzn.to/3dIhtcs) you might as well get that in the first place. That being said the cable

I bought is significantly longer than the one they provide in the pack and that comes in handy to have a bit more moving freedom during studio sessions.

Here’s what it looks like once plugged, to set it as input device inside Logic:

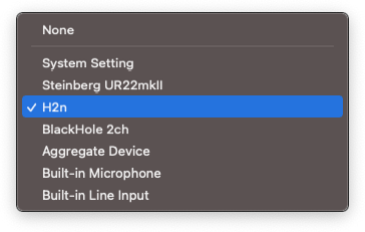
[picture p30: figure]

But if you want to use another audio interface to record instruments, MIDI, and other mics at the
same time (I personally have a Steinberg UR22mkII (https://amzn.to/3ICsjiD) for that), you can’t just switch input device in your DAW like this.

Instead, on macOS, I recommend in Audio MIDI Setup to configure an aggregate device that includes both your sound card and the H2n. This way, you can set that aggregate device as input in your DAW and you’ll get all the channels from your sound card plus all the channels from the Zoom!

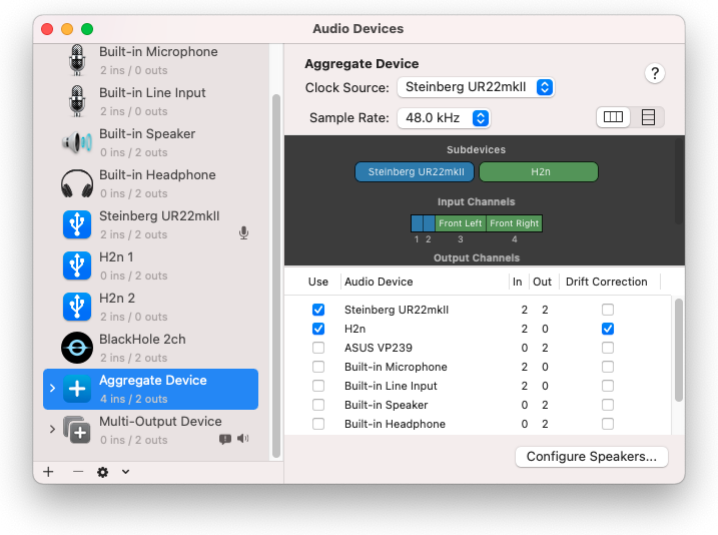
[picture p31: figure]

## Record motorcycle sound, RJ style

As I mentioned earlier Royal Jordanian (https://www.youtube.com/c/royaljordanianR) is a famous motorcycle YouTuber, and makes some of the best sounding motorcycle videos out there.

He records mainly with a H2n and that’s the reason I got one in the first place! But if you’re going to record your motorcycle rides with it, you’ll quickly realize that’s not enough information.

Were to put the H2n?
What recording mode to use?
What direction should the mic be facing?
What gain to use?

Luckily, RJ once made a Q&A video where he shows exactly how he uses is H2n. (https://youtu.be/PVULgH3mOtw?t=9) What I love is that even though it lasts a few seconds, we can see precisely that:

1. The mic is in X-Y stereo mode (arrow pointing to the front of the mic).
2. He puts it in his motorcycle jacket chest pocket.
3. Specifically, the mic is placed facing downwards, with the front of the mic on his chest (so facing towards the back of the motorcycle).

This makes sense, as most of the sound is going to be heard at the exhaust level, which is behind him, and definitely below his chest.

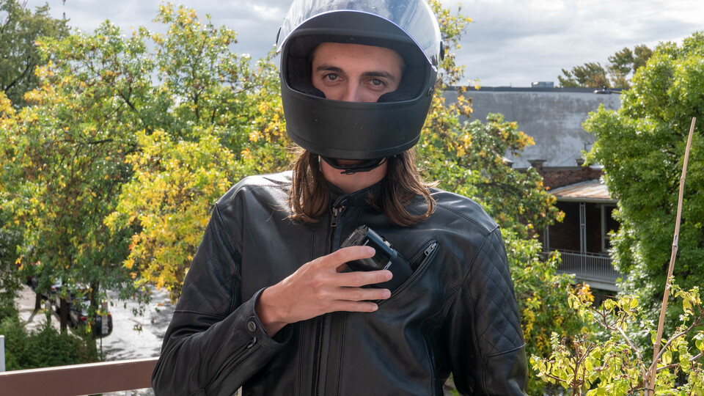
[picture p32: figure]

This leaves us with the question of the gain. That’s gonna be very specific to your jacket and your motorcycle in general, so you should do a couple of tests, going at relatively high revs, to see if it’s clipping or not. When in doubt, I would recommend using a lower gain for this as distorted audio from recording a motorcycle engine quickly gets unusable. Maybe start around 5 and go up or down from there!

I’ll add from my personal experience that it’s a good idea to put the HOLD mode on the right side of the H2n while riding (same button you use to power it on but sliding it up). This will make sure that any accidental contact with buttons around the mic won’t stop the recording or open menus and change random things there.

## The potholder trick

Lastly, I’ll share with you a small trick that I use when I put the Zoom on a hard surface in front of me, like a table or a desk.

If you just leave it directly on the hard surface, it’ll pick up all the vibrations from it as noise, so it’s gonna be especially bad when you take or put objects on the same surface as the Zoom is on.

To avoid that, I just place a potholder below it. Anything similar should work, like a folded towel. With that, it’s much less affected by interactions with the hard surface, giving you a cleaner sound quality overall!

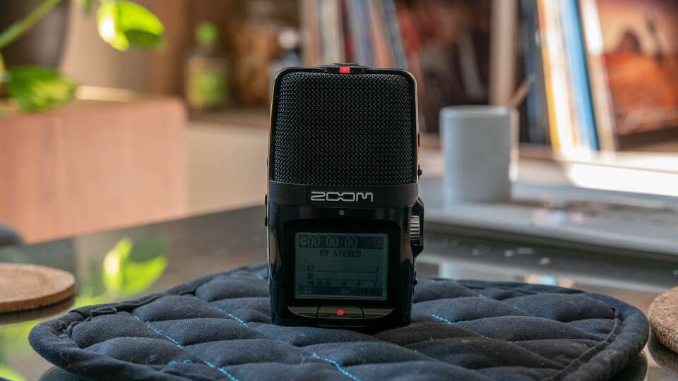
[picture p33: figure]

## Zooming out

That’s it for today! I hope that you learnt a thing or two today thanks to this post. Consider subscribing to my YouTube channel (https://www.youtube.com/FunkyVal) where I also share video versions of those articles (and much more). Happy

recording!

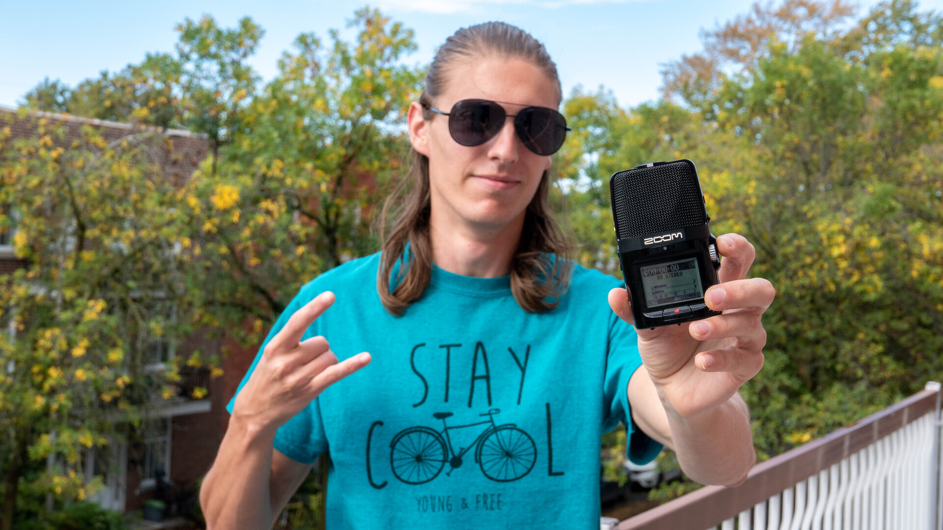
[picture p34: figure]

Want to leave a comment?

Join the discussion on Twitter (https://twitter.com/valeriangalliat/status/1441462405700145154) or send me an email! 💌 This post helped you? Buy me a coffee! (https://ko-fi.com/funkyval) 🍻

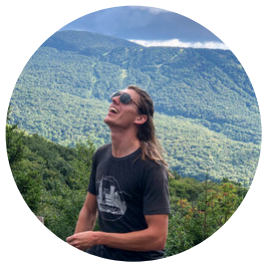
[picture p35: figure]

Made with 🧡 by Val. (https://www.codejam.info/val.html) Generated from a public repository. (https://github.com/valeriangalliat/blog/tree/master/2021/09/zoom-h2n-pro-tips-and-tricks.md)

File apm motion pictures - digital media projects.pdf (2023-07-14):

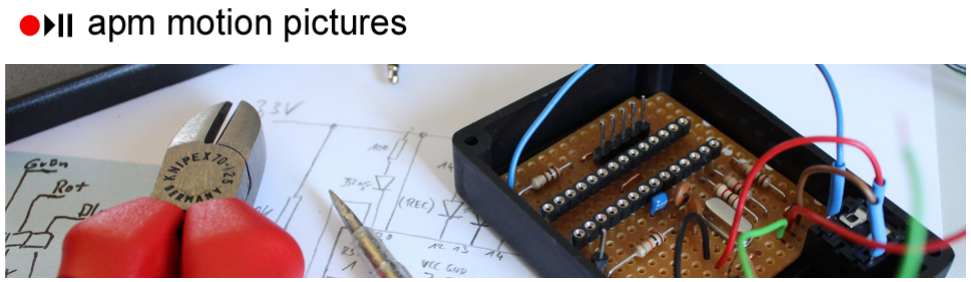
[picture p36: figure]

# DIY Remote Control for Zoom H4n and Canon 60D

last update 30. September 2012

Within this project I developed a remote control for the Zoom H4n portable audio recorder and the Canon 60D DSLR camera. I want to fix a common problem lot of DSLR shooters have: Starting the camera and audio recorder simultaneously!

In my eyes there is problem with the H4n when using with a DSLR - You have to press the record button twice. Especially when filming events (e.g. wedding or birthday) the equipment has to be reliable. But with the H4n you can easily miss to tap the record button twice. As a result the sound partly or completely is missing.

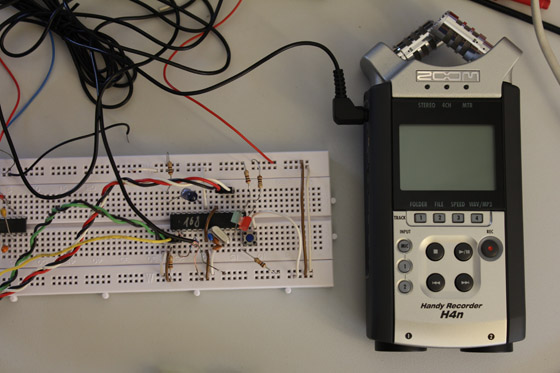
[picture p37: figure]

The remote control prototype circuit connected to Zoom H4n audio recorder.

As said this project shall fix the problem. The goal is to develop an control circuit (like a remote control) that starts the H4n and the Camera (in my case a Canon 60D) with just on button. The requirements are:

Small as possible to be able to put the remote control on the camera body.
Indicator LED for record
Clipping indicator
Optional: AGC with Step-down und Step-up (Note: I decided to skip this point)

The prototype circuit in action.

DIY Zoom H4n r oom H4n remote contr emote control with synchr ol with synchronous camer onous camera st… (https://www.youtube.com/watch?v=2DnmES48jJE)

## H4n Remote Protocol

The protocol is RS232 with 3,3V level at 2400 baud 8n1. Marcus Wolschon has already decoded most parts of the protocol. For further details please see his blog. (http://marcuswolschon.blogspot.de/2012/04/easterhegg-basel-2012.html)

Button Byte 1 Byte 2
Button released 0x80 0x00
Play | 0x82 0x00
Record | 0x81 0x00
Stop | 0x84 0x00
Next | 0x88 0x00
Prev | 0x90 0x00
Volume + | 0x80 0x08
Volume - | 0x80 0x10
RecLevel + | 0x80 0x20
RecLevel - | 0x80 0x40
Mic | 0x80 0x01
Line 1 | 0x80 0x02
Line 2 | 0x80 0x04
LED | Byte
Record | 0x01
Mic red | 0x02
Line 1 red 0x04
Line 2 red 0x08
Mic green 0x10
Line 1 green 0x20
Line 2 green 0x40

Before H4n will reacts on commands from a remote control a registration sequence is needed.

Sender Byte | Description
RC4* 0x00 Send until H4n sends response.
H4n | 0x80
RC4 | 0xA1
H4n | 0x80
*RC4 is the name of the Remote Control


Pinout of H4n Remote Jack

## Controlling the camera (Canon 60D)

The easiest way to control the camera is through a IR remote control. The protocol is simple and available at doc-diy.net. (http://www.doc-diy.net/photo/rc-1_hacked/) The good with IR is - it works for other canon cameras (i.e. ti rebel / D500) too.

## Creating the Circuit

I used the ATMega168 Microcontroller from Atmel because it was available at the moment, you can also use a 'smaller' controller. A little program is used to sent commands to the H4n and to generate the IR signals for the Canon 60D. The circuit is powered by 3,3V through the remote jack on H4n directly, no additional power supply or battery required.

The start/stop trigger button is not build into the housing but connected through a jack and dedicated wire. With this the button can be placed anywhere for more flexibility. Two LEDs are used to indicate recording state and audio clipping. I used low current LEDs for this purpose as I do not know how much power the H4n remote jack can handle, so I am on the save side here.

Download C source code (http://www.apm-motionpictures.de/h4ncontrol/h4nremote.zip)
Download schematic (http://www.apm-motionpictures.de/h4ncontrol/diy_h4n_remote_schematic.png)


The DIY remote control


Schematic (click to enlarge)


>


Author: Andreas Mehler

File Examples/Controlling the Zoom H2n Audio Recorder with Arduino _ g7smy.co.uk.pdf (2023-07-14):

In Part One (https://www.g7smy.co.uk/2017/04/hacking-the-zoom-h2n-remote/) I covered the byte codes sent by the Zoom Remote Controller RC1 and decoded data sent over the wire to the remote from the Zoom H2n Recorder.

In this post I will be covering the use of an Arduino style micro-controller to decode the signals sent by the remote, then control the recorder. I have used a Tennsy 3.1 Arduino clone as this is a small controller with two additional hardware serial ports, works with 3.3volt logic, and a with the addition of a crystal and button battery a real-time clock.


Arduino control of the Zoom H2n

Setup and Connections

The connections on the remotes four pin 2.5mm jack, with pin one being the tip:

1. Remote Receive – RX
2. Remote Transmit – TX
3. Ground

ARDUINO, (https://www.g7smy.co.uk/category/arduino/) ELECTRONICS, (https://www.g7smy.co.uk/category/electronics/) HARDWARE, (https://www.g7smy.co.uk/category/hardware/) INTERESTING (https://www.g7smy.co.uk/category/interesting/)

# CONTROLLING THE ZOOM H2N AUDIO RECORDER WITH ARDUINO

17TH APRIL 2017 (https://www.g7smy.co.uk/2017/04/controlling-the-zoom-h2n-audio-recorder-with-arduino/) | KARL (https://www.g7smy.co.uk/author/kmcauley/)

## g7smy.co.uk

4. 3.1V – Power

On the Teensy there are two hardware serial UARTs available in addition to that used by the USB port, UART2: Pin 9 (RX2), Pin 10 (TX2) and UART3: Pin 7 (RX3), Pin 8 (TX3). Serial data is sent at 2400 baud, 8 bits, no parity, 1 stop (8n1). The response data shown is for when the recorder is in XY Stereo mode (0x20, 0x21), different codes are returned when other recording modes are used, see the end of Part One (https://www.g7smy.co.uk/2017/04/hacking-the-zoom-h2n-remote/) for details.

Serial Monitor

This first chunk of code is for monitoring the outputs of the remote control and recorder. Connect Remote Receive – RX on the remote to RX2 – Pin 9 on the Teensy and Remote Transmit – TX to RX3 – Pin 7 and Ground to Ground on the Teensy. This program will output data received to the Arduino IDE’s serial monitor.

The output is in four columns; the UART seeing activity, current milliseconds and the received data in hexadecimal and decimal values.

Taking Control – But Not Listening

Sending the command to the recorder blindly is quite straight forward, just send the bytes to the Remote Transmit – TX pin on the recorder (Zoom RX). This can be seen in the following, when run it starts the recorder recording for ten seconds. Connect: Remote TX to TX2 on the Teensy, Remote RX to RX2 and Ground to Ground.

1 | //written for a Teensy 3.x
2 | #define MONITOR_LED 13
3 | int incomingByte2 = 0;
4 | int incomingByte3 = 0;
5 | unsigned long nowMillis = 0;
6
7 | void printByte(int p, int b) {
8 | char out[40];
9 | sprintf(out, "RX%d: %8lu\t0x%x\t%d",p,nowMillis,b,b);
10 | Serial.println(out);
11 | }
12
13 | void setup() {
14 | delay(1000);
15 | Serial.begin(9600);
16 | Serial.println("ready");
17
18 | // incoming data
19 | Serial2.begin(2400, SERIAL_8N1); // Remote Receive - RX
20 | Serial3.begin(2400, SERIAL_8N1); // Remote Transmit - TX
21
22 | pinMode(MONITOR_LED, OUTPUT);
23 | digitalWrite(MONITOR_LED, HIGH);
24 | }
25
26 | void loop() {
27

//written for a Teensy 3.x #define MONITOR_LED 13

Taking Control – And Listening for a Reply

The next stage is to have the Teensy control the Zoom and listen for a response from the recorder. Again, as before connect: Remote TX to TX2 on the Teensy, Remote RX to RX2 and Ground to Ground. For the demonstration I have added three buttons to act as the controller.


Zoom Control with three buttons
The following code needs more development work, I ran out of time, but I think gives a good starting point for further investigation. I have placed the commands for the remote in a structure, (http://playground.arduino.cc/Code/Struct) each command; record, pause and mark has four components, the command to transmit to the Zoom, the expected responses when starting and stopping and a flag to store the status.
7 | void zoomTX(int d[], int len) {
8
9 | // show what is going to be done
10 | for (int i = 0; i < len; i++) {
11 | char out[40];
12 | if (d[i] < 0) {
13 | sprintf(out,"TX2: delay(%d)",abs(d[i]));
14 | Serial.println(out);
15 | }
16 | else {
17 | sprintf(out, "TX2: %d\t0x%x", i, d[i]);
18 | Serial.println(out);
19 | }
20 | }
21
22 | // do the command
23 | for (int i = 0; i < len; i++) {
24 | if (d[i] < 0) {
25 | delay(abs(d[i]));
26 | }
27 | else {

// bytes to start and stop the recorder, a negative number is used as a delay int record[5] = { 0x81, 0x0, -100, 0x80, 0x0 };

1 | //written for a Teensy 3.x
2
| #define MONITOR_LED 13
| #define RED_BTN 2
| #define GRN_BTN 3

There is a problem when resuming from pause, because the Zoom sends codes to flash the LED on the remote this can pick up the wrong pair of bytes; such as 0x21 0x21 instead of the expected 0x20 0x21.

I expect to be revisiting this, adding a timer function plus external battery for long running. I’m not sure how useful listening for a response is, sending the record command toggle on its own seems fairly robust without the need to check.

Links and Sources

Teensy UART details (https://www.pjrc.com/teensy/td_uart.html)
DIY Remote Control for Zoom H4n and Canon 60D (http://www.apm-motionpictures.de/en/h4ncontrol)

#define BLU_BTN 4

| unsigned long nowMillis = 0;
| unsigned long prevMillis = 0;
10 | unsigned long buttonPressDelay = 400;
11 | unsigned long serialTimeout = 8000; // it can take a few seconds for the zoom to start recor
12
13 | struct ZOOMTX {
14 | int record[4][5] = { {0x81, 0x0, -100, 0x80, 0x0}, // Transmit command data - a minus nu
15 | {0x20, 0x20, 0x21}, // Expected Response - Start (in XY S
16 | {0x21, 0x21, 0x20}, // Response - Stop
17 | {0} }; // status: record[3][0] = 1: recordin
18 | int pause[4][5] = { {0x80, 0x2, -100, 0x80, 0x0},
19 | {0x21, 0x21, 0x20},
20 | {0x20, 0x21},
21 | {0} };
22 | int mark[4][5] = { {0x80, 0x1, -100, 0x80, 0x0},
23 | {0x20, 0x20},
24 | {0x20, 0x20},
25 | {0} };
26

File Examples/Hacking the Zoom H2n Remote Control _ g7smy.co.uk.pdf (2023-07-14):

The Zoom H2n is a portable sound recorder looking like an old fashioned microphone it is a handheld device that provides an assortment of stereo and surround recording modes, it records onto an SD card in MP3 or WAV format with options for various bitrates and frequencies. The unit is powered internally by two AA batteries and can also be powered from the USB port. The recorder I am experimenting on has firmware version 2.00 installed.


A not at all contrived image of the Zoom H2n Portable Recorder
The Zoom Remote Controller RC2 is a wired four pin 2.5mm jack plug connection, this remote has three buttons: record, mark, and pause there is also an LED to show when the H2n is recording. It is purchased separately from the recorder and only appears to be available bundled in an accessory pack. It looks difficult to take apart without leaving some damage, and this may not be necessary for decoding.

ARDUINO, (https://www.g7smy.co.uk/category/arduino/) ELECTRONICS, (https://www.g7smy.co.uk/category/electronics/) HARDWARE, (https://www.g7smy.co.uk/category/hardware/) INTERESTING (https://www.g7smy.co.uk/category/interesting/)

# HACKING THE ZOOM H2N REMOTE CONTROL

14TH APRIL 2017 (https://www.g7smy.co.uk/2017/04/hacking-the-zoom-h2n-remote/) | KARL (https://www.g7smy.co.uk/author/kmcauley/)

## g7smy.co.uk


Zoom Remote and breadboard for testing
In this post I am looking to see how the remote works and find what control method it employs so in Part Two (https://www.g7smy.co.uk/2017/04/controlling-the-zoom-h2n-audio-recorder-with-arduino/) I can use an Arduino style micro-controller to provide an external trigger such as for timed recordings.

Setup for Testing

For testing I have made a breakout lead, this is essentially an extension cable split in half with a couple of molex style connectors allowing me to plug it into a breadboard. With this I have found the cable has the following connections, with pin one being the tip of the 2.5mm jack plug:

1. Remote Receive – RX
2. Remote Transmit – TX
3. Ground
4. 3.1V – Power

When checking with a multimeter I found continuity from the negative of the left battery (on the Mic Gain side) to pin three, ground, of the jack, there is also a connection between the positive of the right-hand battery to pin one of the jack but on the multimeter in diode mode there looks to be a capacitor, the voltage rises until no apparent connection is indicated. With no activity on the recorder the RX and TX pins show ~2.7 volts.

Determining the RX and TX pins turned out to be straightforward. When you press the record button after a moment the recording LED lights up, on the oscilloscope I can see three different square wave patterns for the three different buttons on the TX pin and a single type of square wave on RX to light the LED. The following images show the signal for the record button then that sent in response to to light the LED.


Signalsent by the remote when Record pressed


Signalsent by the Zoom recorder to light the LED in the remote
Also when buttons are pressed on the recorder data is seen on the RX line. For a more detailed examination I will need to break out the logic analyser.

Signal Analysis

Following some research where the remote for a Zoom H4n was examined, (http://marcuswolschon.blogspot.co.uk/2012/04/easterhegg-basel-2012.html) I set both channels being used on the logic analyser to the following:

Protocol: UART
2400 baud, 8 bits, no parity, 1 stop (8n1) Bit Order: LSB first, inverted logic: No


Decoding of the first part of the stop recording command
First I decoded the buttons on the remote with the trigger on the logic analyser set to falling edge on the Remote TX line. On TX there is a pause between the two pairs of command bytes which appears to be the length of time the button was pressed, around 350-500ms, there is also a pause between bytes in the RX response, the value of the response changes depending on which recording mode you are in, those shown below are when the recorder is in XY Stereo:

Record Start

TX: | 0x81 0x0 | ~ | 0x80 0x0
RX: | 0x20 | 1.85s | 0x20 0x21 | record LED on

Record Stop

TX: | 0x81 0x0 | ~ | 0x80 0x0
RX: | 0x21 0x21 0x20 | 1.9s | 0x20 0x20 | record LED off

Pause (while recording)

TX: | 0x80 0x2 | ~ | 0x80 0x0
RX: | 0x21 | 51ms | 0x21 0x20 | then this repeats
| | 492ms | 0x20 0x21 | to flash the LED
| | 492ms | 0x21 0x20 | until pause is pressed again

Resume from Pause

TX: | 0x80 0x2 | ~ | 0x80 0x0
RX: | 0x21 0x21 | | | LED on

Mark

TX: | 0x80 0x1 | ~ | 0x80 0x0

RX: | 0x21 | 492ms | 0x20 0x21 | LED on

I was also able to capture the following activity sent to the remote when various buttons were pressed on the recorder itself with the recorder in XY Stereo mode. Other models of the recorders made by Zoom have more advanced remotes, such as the RC4 as featured in this hack (http://marcuswolschon.blogspot.co.uk/2012/04/easterhegg-basel-2012.html) of the H4n. I suspect they would work on this machine too. This time I set the logic analyser to trigger with a falling edge on Remote RX. I think the 0x20 code is used to indicate the display illumination has been turned off. I saw activity on all buttons except the Mic Gain knob.

Power On – Without remote attached

TX: | Lots of random activity
RX: | 0x10 | 400ms | 0x80 0x81
| | 1.2s | 0x10 0x0 0x80 0x0
| | 140ms | 0x0 0x0 0x80 0x80 0x0
| | ~2ms | 0x0 0x80 0x0 0x0 0x80 0x0

Power On – With remote attached

TX: | 0x0 | five pulses 30ms apart
| 30ms | 0x0 0xA1 0x80 0x0 0xA1
RX: | following pulses on TX | 0x80 0x81 0x80 0x10
| 1.2s | 0x10 0x0
| 148ms | 0x0 0x0
| ~4ms | 0x0 0x0 0x0

Record Start

RX: | 0x20 | 20ms | 0x20 0x21 | LED on

Record Stop

RX: | 0x21 0x21 0x21 0x20 | ~ | 0x20
| | ~283ms | 0x20 0x20 | LED off

Menu \ Home – Into Menu

RX: | 0x20 0x20 0x0

Exit from Menu

RX: | 0x20 | 45ms | 0x20

Play Switch: Up/Down/Press

RX: | 0x20 | 55ms | 0x20

Clipping detect (tapping the microphone with a pen)

RX: | 0x10 0x2 | 56ms | 0x2
| | 59ms | 0x10
| | 60ms | 0x10
| | 354ms | 0x10

Volume: Up and Down

RX: | 0x20

Recording Mode Change: 4 channel surround

RX: | 0x10 0x10 0x30 | 14ms | 0x30 0x30
| | 122ms | 0x34
| | 60ms | 0x30
| | 60ms | 0x30

Recording Mode Change: XY Stereo

RX: | 0x30 0x30 0x20 | 216ms | 0x20

Recording Mode Change: 2 channel surround

RX: | 0x20 0x20 0x30 0x30 | 18ms | 0x30
| | 148ms | 0x30
| | 164ms | 0x30 0x6
| | 56ms | 0x14 0x30
| | 477ms | 0x30

Recording Mode Change: MS Stereo

RX: | 0x30 0x30 0x10 | 170ms | 0x10
| | 50ms | 0x12

I think these response codes are to light up various LED’s on the more advanced Zoom RC4 remote, this suggests that other remotes would work in this recorder.

The following table shows the response codes given with different microphone configurations when record is clicked to start recording:

0x81 0x0 ~100ms delay 0x80 0x0; XY Stereo:; 0x20 750ms delay 0x20 0x21; 2 Channel Surround:; 0x30 750ms delay 0x30 0x31; MS Stereo:; 0x10 750ms delay 0x10 0x11; 4 Channel Surround:; control.; Links and Sources; Manufacturers Page: Zoom H2n Hacking the Zoom H4n remote Logic Analyser: https://www.ikalogic.com/scanaplus/

In Part Two (https://www.g7smy.co.uk/2017/04/controlling-the-zoom-h2n-audio-recorder-with-arduino/) I will be covering the use of a Arduino style micro-controller as an alternative remote

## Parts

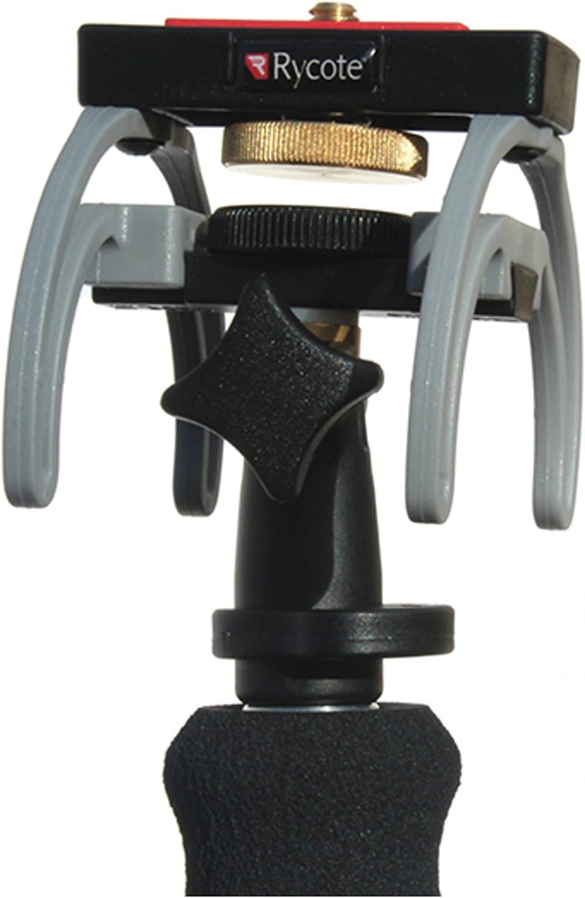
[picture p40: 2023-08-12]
parts/zeb/71H252vEVGL._AC_SL1500_.jpg

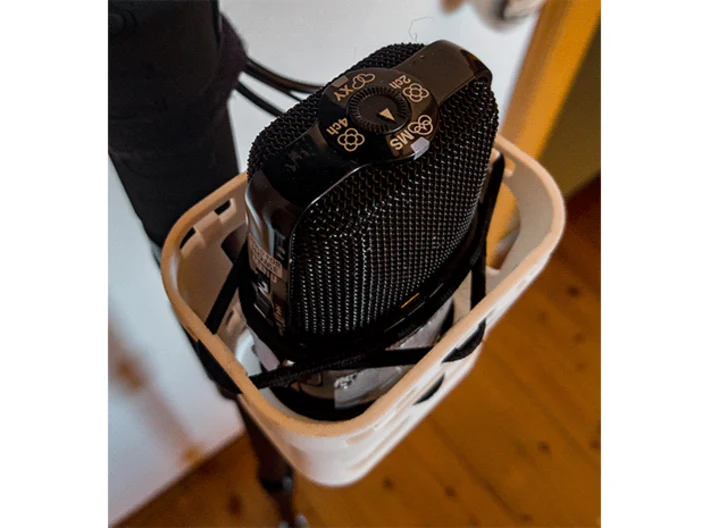
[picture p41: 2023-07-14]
parts/mount_bucket/710x528_24930612_13535316_1687498347_1_0.jpg

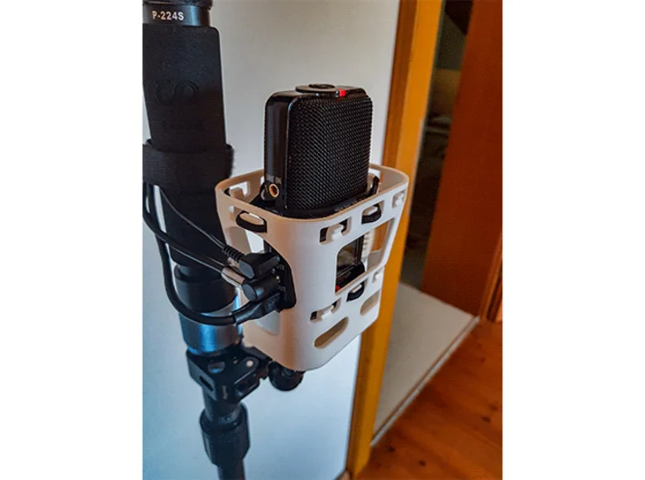
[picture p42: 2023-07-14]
parts/mount_bucket/710x528_24930609_13535316_1687498347_1_0.jpg

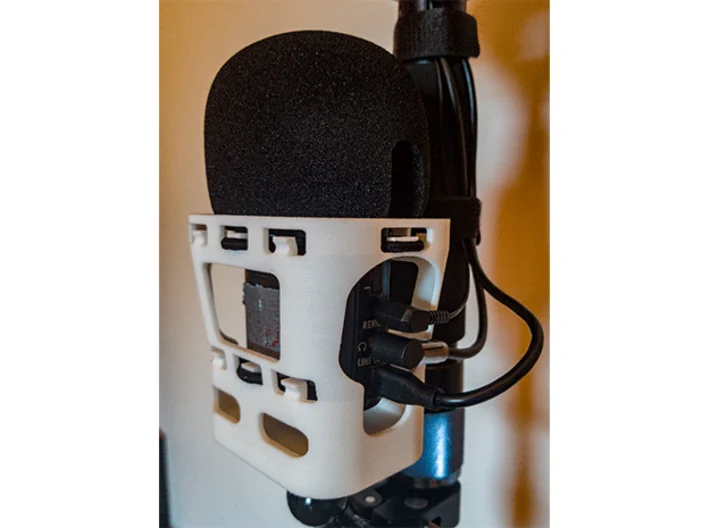
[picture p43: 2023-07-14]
parts/mount_bucket/710x528_24930611_13535316_1687498347_1_0.jpg

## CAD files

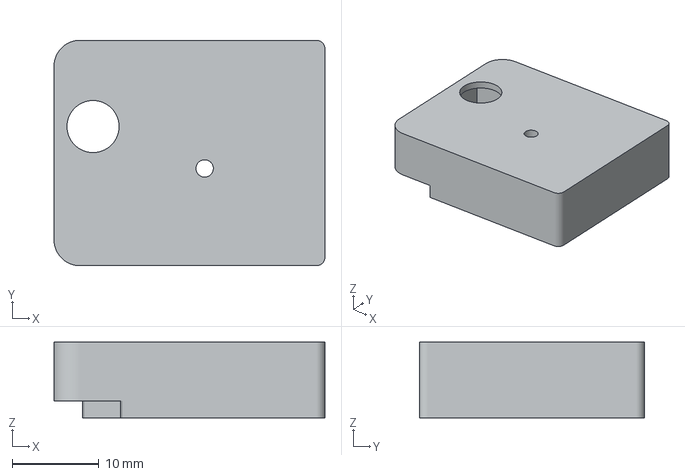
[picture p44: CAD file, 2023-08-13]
parts/cr20/CaseFront_7.3mf
31.2 x 26.0 x 8.75 mm

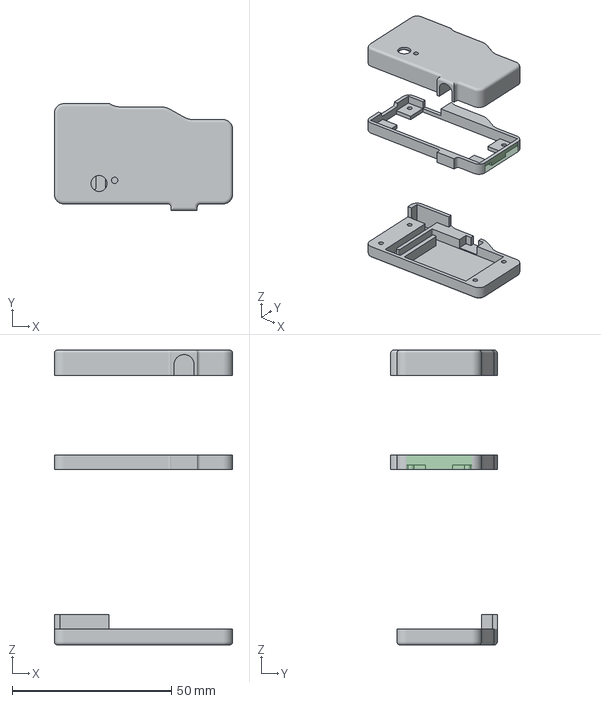
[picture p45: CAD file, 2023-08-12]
parts/FrameFor_RP2040_08.3mf
55.9 x 33.5 x 92.5 mm
FrameFor_RP2040_08 x 3

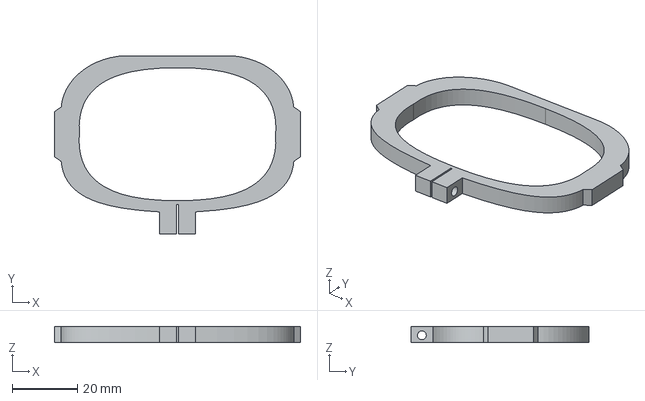
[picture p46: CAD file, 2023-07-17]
parts/mount_bucket/BaseCup_brim_04.stp
75.3 x 54.6 x 5.00 mm

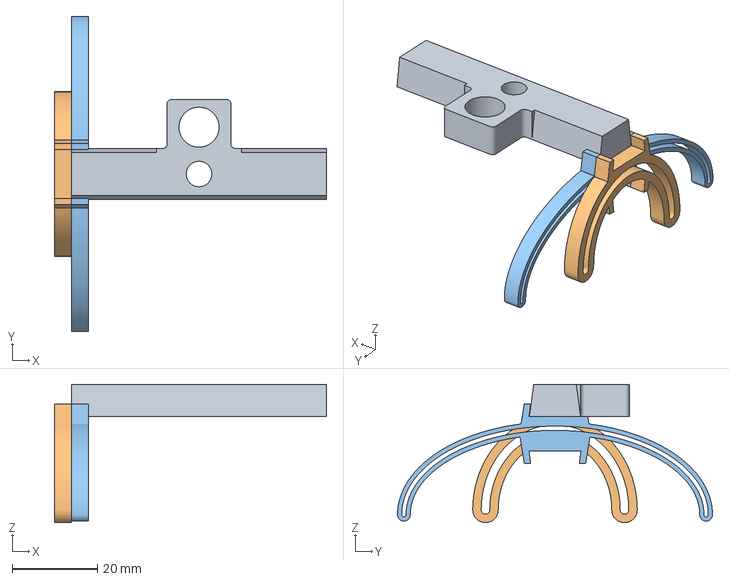
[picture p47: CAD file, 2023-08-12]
parts/zeb/bar_02.3mf
64.0 x 74.0 x 32.5 mm
bar_02 x 3

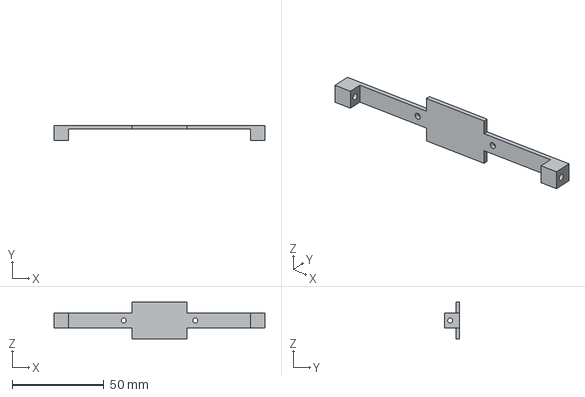
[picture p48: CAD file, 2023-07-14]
timelapse/pi3/CamBase01.stp
115.0 x 8.31 x 20.0 mm

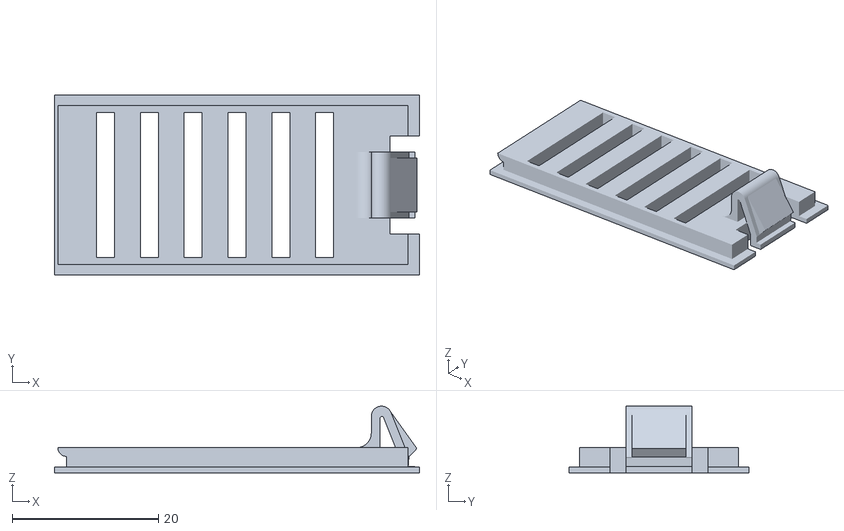
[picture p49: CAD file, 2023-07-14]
timelapse/pi3/Raspberry_Pi_7_Inch_Touchscreen_display_case_1585924/files/Raspi7inch_SD_Hatch.stl
50.0 x 24.6 x 9.13

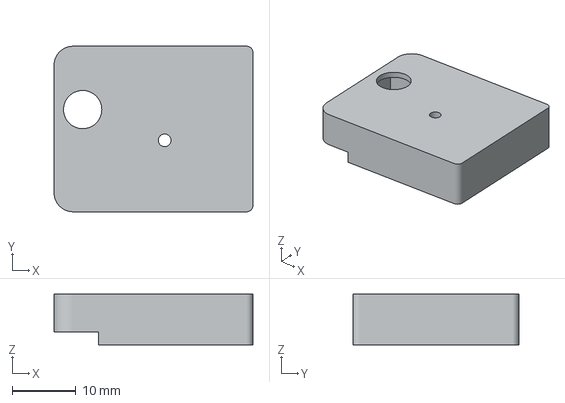
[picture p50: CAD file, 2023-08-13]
parts/cr20/CaseFront_4.3mf
31.2 x 26.0 x 8.00 mm

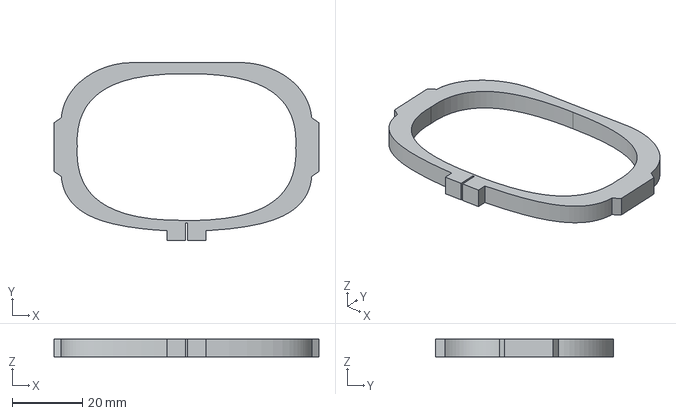
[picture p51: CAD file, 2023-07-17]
parts/mount_bucket/BaseCup_brim_03.stp
75.3 x 50.5 x 5.00 mm

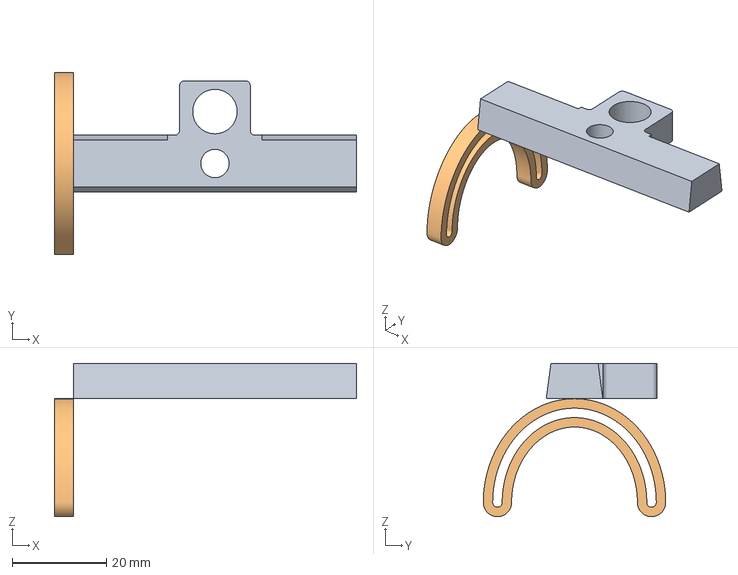
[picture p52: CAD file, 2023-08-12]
parts/zeb/bar_01.3mf
64.0 x 38.7 x 32.5 mm
bar_01 x 2

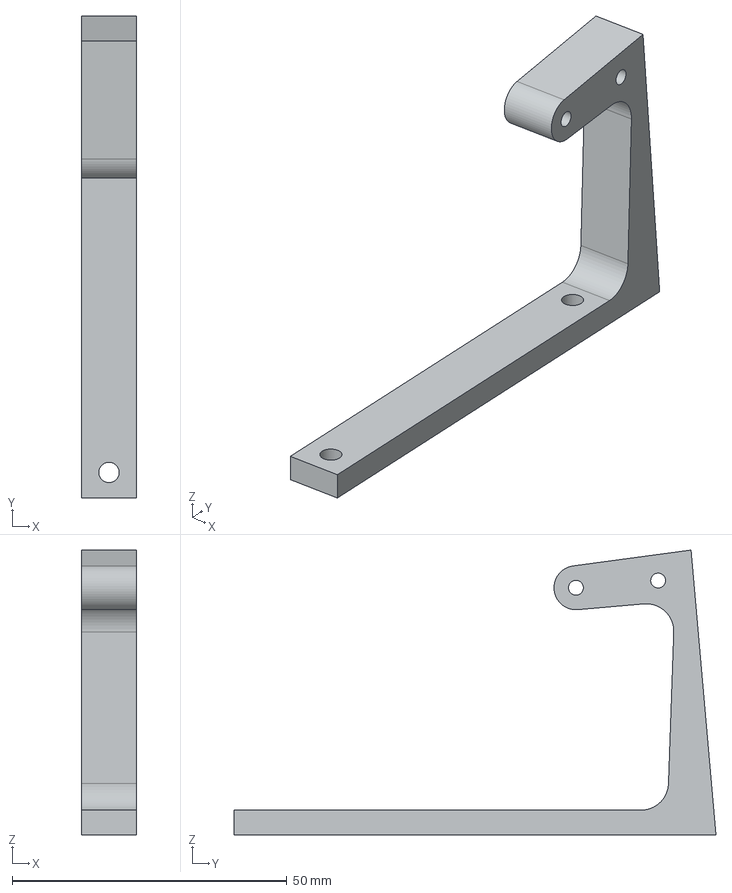
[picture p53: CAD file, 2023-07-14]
timelapse/pi3/Leg_01.stp
10.0 x 87.7 x 51.8 mm

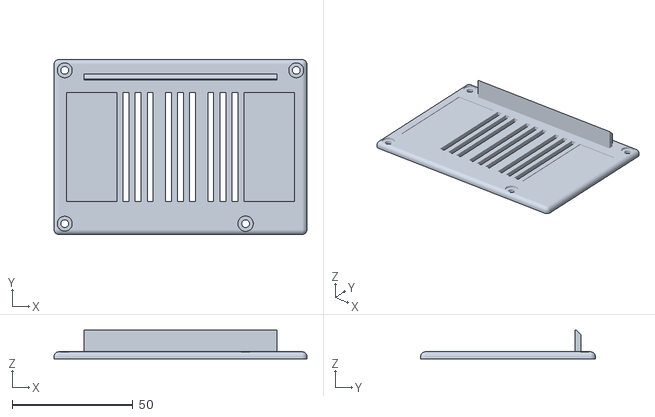
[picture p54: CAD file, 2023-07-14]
timelapse/pi3/Raspberry_Pi_7_Inch_Touchscreen_display_case_1585924/files/Raspi7inch_Lid_Velcro_2cm_HDD_Rest.stl
104.8 x 72.4 x 12.0

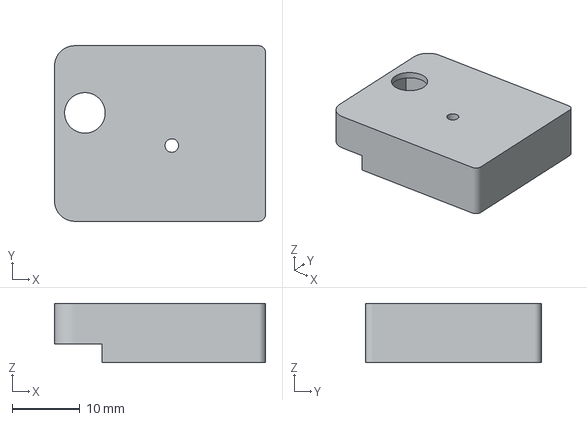
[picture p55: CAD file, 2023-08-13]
parts/cr20/CaseFront_6.3mf
31.2 x 26.0 x 8.75 mm

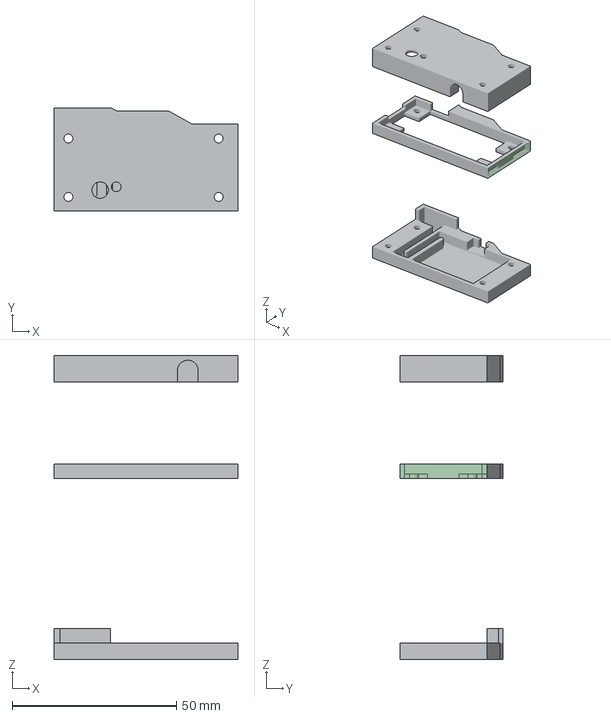
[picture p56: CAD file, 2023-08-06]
parts/FrameFor_RP2040_06.3mf
55.9 x 31.5 x 92.5 mm
FrameFor_RP2040_06 x 3

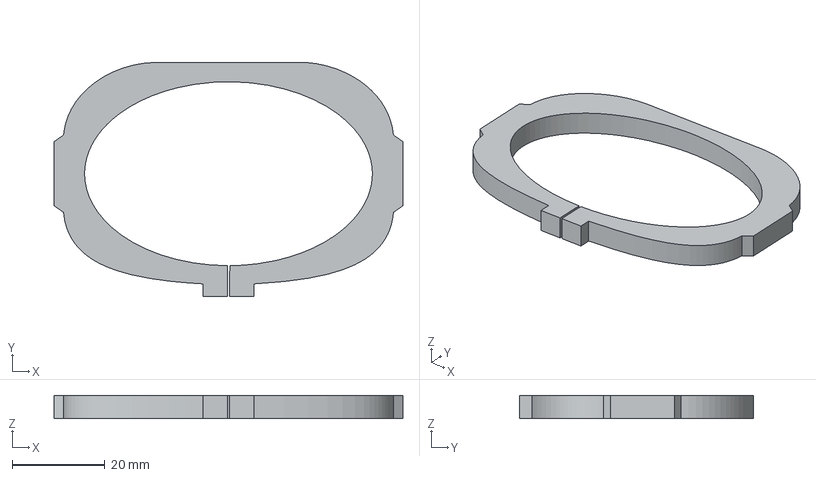
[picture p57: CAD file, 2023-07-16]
parts/mount_bucket/BaseCup_brim_01.stp
75.3 x 50.5 x 5.00 mm

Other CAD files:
parts/FrameFor_RP2040_08_chamfer.3mf
parts/zeb/bouncy_base_02.stp
timelapse/pi3/Raspberry_Pi_7_Inch_Touchscreen_display_case_1585924/files/Raspi7inch_Case.stl
parts/cr20/CaseFront_5.3mf
parts/FrameFor_RP2040_00.3mf
parts/FrameFor_RP2040_01.3mf
parts/FrameFor_RP2040_02.3mf
parts/FrameFor_RP2040_03.3mf
parts/FrameFor_RP2040_04.3mf
parts/FrameFor_RP2040_05.3mf
parts/FrameFor_RP2040_07.3mf
parts/cr20/CaseFront_0.3mf
parts/cr20/CaseFront_1.3mf
parts/cr20/CaseFront_2.3mf
parts/cr20/CaseFront_3.3mf
parts/mount_bucket/BaseCup_brim_02.stp
parts/mount_bucket/Bucket_01.stp
parts/mount_bucket/LowStrap_01.stp
parts/mount_bucket/LowStrap_brim_01.stp
parts/mount_bucket/LowStrap_brim_02.stp
parts/mount_bucket/LowStrap_brim_03.stp
parts/mount_bucket/LowStrap_brim_04.stp
parts/zeb/bouncy_base_01.stp
parts/zeb/bouncy_base_03.stp
parts/zeb/bouncy_base_04.stp
parts/zeb/slide01_x4.3mf
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

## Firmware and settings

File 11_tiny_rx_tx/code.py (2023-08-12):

import PulseDecoder
import time
import board
import pwmio
import busio


AMBER = (255, 191, 0)
RED = (255, 0, 0)
RED_DIM = (100, 0, 0)
GREEN = (0, 255, 0)
GREEN_DIM = (0, 100, 0)
BLUE = (0, 0, 255)


#Setup RGB LED
# Construct PWM objects with RGB LED
rpwm = pwmio.PWMOut(board.LED_R, frequency=1000) # RED GP18
gpwm = pwmio.PWMOut(board.LED_G, frequency=1000) # GREEN GP19
bpwm = pwmio.PWMOut(board.LED_B, frequency=1000) # BLUE GP20

# Turn off
rduty = 65535
gduty = 65535
bduty = 65535
rpwm.duty_cycle = rduty
gpwm.duty_cycle = gduty
bpwm.duty_cycle = bduty

def LED(RGB):
    r,g,b = RGB
    rduty = int(65535 -(65535 * r/255))
    gduty = int(65535 -(65535 * g/255))
    bduty = int(65535 -(65535 * b/255))
#    print(rduty)
#    print(gduty)
#    print(bduty)
    rpwm.duty_cycle = rduty
    gpwm.duty_cycle = gduty
    bpwm.duty_cycle = bduty

def print_byte(p, b):
    print("RX{}: {:8}\t0x{:x}\t{}".format(p, int(time.monotonic() * 1000), b, b))

def interpret_byte(byte):
    # Bit 7 - Handshake phase (1 for handshake, 0 for acknowledged)
    handshake_phase = bool(byte & 0b10000000)
    # Bit 0 - Recording in progress (alternates 0 and 1 when recording paused)
    recording_in_progress = bool(byte & 0b00000001)
    # Print the decoded properties
    print("Handshake phase:{} Recording in progress:{}".format(handshake_phase,recording_in_progress))

def needsHandshake(byte):
    handshake_phase = bool(byte & 0b10000000)
    return handshake_phase

def isRecording(byte):
    # Bit 7 - Handshake phase (1 for handshake, 0 for acknowledged)
    handshake_phase = bool(byte & 0b10000000)
    # Bit 0 - Recording in progress (alternates 0 and 1 when recording paused)
    recording_in_progress = bool(byte & 0b00000001)
    # Print the decoded properties
    return not handshake_phase and recording_in_progress


uart2 = busio.UART(board.GP4, board.GP5, baudrate=2400, bits=8, parity=None, stop=1)



print("Flusing UART")
# Flush UART buffer
while uart2.in_waiting > 0:
    _ = uart2.read(1)
print("Done flusing UART")

decoder = PulseDecoder.PulseDecoder(_IR_Pin=board.GP29)


print("Begin reading from UART 2")

LED(AMBER)

# Variable to store the last received time
last_received_time = time.monotonic()
stateKnown = False
stateIsRecording = False

print("Starting loop")
while True:

    # Handle any incoming data on serial 2
    while uart2.in_waiting > 0:
        LED(BLUE)
        incoming_byte2 = uart2.read(1)[0]
         # Update the last received time
        print_byte(2, incoming_byte2)
        interpret_byte(incoming_byte2)
        if not needsHandshake(incoming_byte2):
            # This useful status  data
            stateIsRecording = isRecording(incoming_byte2)
            print("Updated status. Record={}".format(stateIsRecording))
            last_received_time = time.monotonic()
            stateKnown = True
            if stateIsRecording:
                LED(RED)
            else:
                LED(GREEN)

    # Nothing to read from serial 2 right now
    if not stateKnown:
        LED(AMBER)
        if time.monotonic() - last_received_time >= 5.0:
            print("No status data received for 5 seconds. Performing handshake.")
            # This code elicits a response
            uart2.write(b'\x80')
            time.sleep(0.01)
            uart2.write(b'\x00')
            time.sleep(0.01)
            uart2.write(b'\xA1')
            time.sleep(0.01)
            uart2.write(b'\x00')
            time.sleep(0.25)
            last_received_time = time.monotonic()

    decodedCode = decoder.getCode()
    if not decodedCode == None:
        if isinstance(decodedCode, str) and len(decodedCode) == 32:
            # Skip the first 16 bits and extract the next 5 bits
            five_bit_substring = decodedCode[16:21]
            # Convert the 5-bit substring to an integer
            color_value = int(five_bit_substring, 2)
            # Print the result
            print("Color value as an integer:", color_value)
            if color_value == 28: # Green On button
                
                if not stateIsRecording:
                    LED(GREEN_DIM) # Wink to show you are doing something
                    # Let's try start recording?
                    print("Send start recording")
                    uart2.write(b'\x81')
                    time.sleep(0.1)  # 100ms delay
                    uart2.write(b'\x00')
                    time.sleep(0.1)  # 100ms delay
                    uart2.write(b'\x80')
                    time.sleep(0.1)  # 100ms delay
                    uart2.write(b'\x00')
                    time.sleep(0.25)
                    print("Done sending start recording")
                    LED(GREEN)
            elif color_value == 12: # Red Off button
                if stateIsRecording:
                    LED(RED_DIM)  # Wink to show you are doing something
                    print("Send stop recording")
                    # Let's try stop recording?
                    uart2.write(b'\x81')
                    time.sleep(0.1)  # 100ms delay
                    uart2.write(b'\x00')
                    time.sleep(0.1)  # 100ms delay
                    uart2.write(b'\x80')
                    time.sleep(0.1)  # 100ms delay
                    uart2.write(b'\x00')
                    time.sleep(0.25)
                    print("Done sending stop recording")
                    LED(RED)
        else:
            print(decodedCode)

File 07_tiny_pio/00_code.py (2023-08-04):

# Tiny 2040 RBG LED control
# Original Micro Python code by Tony Goodhew 11th March 2021
# Ported to Circuit Python

import time
import board
import pwmio
import rp2pio
import adafruit_pioasm


#Setup RGB LED
# Construct PWM objects with RGB LED
rpwm = pwmio.PWMOut(board.LED_R, frequency=1000) # RED GP18
gpwm = pwmio.PWMOut(board.LED_G, frequency=1000) # GREEN GP19
bpwm = pwmio.PWMOut(board.LED_B, frequency=1000) # BLUE GP20

# Turn off
rduty = 65535
gduty = 65535
bduty = 65535
rpwm.duty_cycle = rduty
gpwm.duty_cycle = gduty
bpwm.duty_cycle = bduty

def LED(r,g,b):
    rduty = int(65535 -(65535 * r/255))
    gduty = int(65535 -(65535 * g/255))
    bduty = int(65535 -(65535 * b/255))
#    print(rduty)
#    print(gduty)
#    print(bduty)
    rpwm.duty_cycle = rduty
    gpwm.duty_cycle = gduty
    bpwm.duty_cycle = bduty

LED(255,255,255)
time.sleep(0.3)
LED(255,0,0)
time.sleep(0.3)

# Blink
#while True:
for _ in range(100):
    LED(0,0,255)
    time.sleep(0.3)
    LED(0,255,0)
    time.sleep(0.3)
    LED(255,0,0)
    time.sleep(0.3)
    
https://learn.adafruit.com/intro-to-rp2040-pio-with-circuitpython/using-pio-to-blink-a-led-quickly-or-slowly

# SPDX-FileCopyrightText: 2021 Jeff Epler, written for Adafruit Industries
#
# SPDX-License-Identifier: MIT
#
# Adapted from the example https://github.com/raspberrypi/pico-examples/tree/master/pio/pio_blink


blink = adafruit_pioasm.assemble(
    """
.program blink
    pull block    ; These two instructions take the blink duration
    out y, 32     ; and store it in y
forever:
    mov x, y
    set pins, 1   ; Turn LED on
lp1:
    jmp x-- lp1   ; Delay for (x + 1) cycles, x is a 32 bit number
    mov x, y
    set pins, 0   ; Turn LED off
lp2:
    jmp x-- lp2   ; Delay for the same number of cycles again
    jmp forever   ; Blink forever!
"""
)


while True:
    for freq in [5, 8, 30]:
        with rp2pio.StateMachine(
            blink,
            frequency=125_000_000,
            first_set_pin=board.LED,
            wait_for_txstall=False,
        ) as sm:
            data = array.array("I", [sm.frequency // freq])
            sm.write(data)
            time.sleep(3)
        time.sleep(0.5)

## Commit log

2023-07-14 First commit of useful stuff.
    [CamBase01.stp, Leg_01.stp, Raspi7inch_Case.stl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]
2023-07-14 Submitted camera to wrong repo
    [timelapse.py]
2023-07-16 Success reading IR with PIO
    [Bucket_01.stp, LowStrap_01.stp, LowStrap_brim_01.stp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]
2023-07-16 Missed files
    [BaseCup_brim_01.stp, BaseCup_brim_02.stp]
2023-07-16 Saving changes to configure camera res
2023-07-17 Saving update with lots of wins!
    [BaseCup_brim_03.stp, BaseCup_brim_04.stp, bouncy_base_01.stp]
2023-07-17 Organising some stuff
    [CamBase01.stp, Leg_01.stp, Raspi7inch_Case.stl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]
2023-07-18 More mount part designs
    [slide01_x4.3mf, slide02_x4.3mf]
2023-07-23 Received RX from zoom to pico
    [bouncy_base_02.stp, bouncy_base_03.stp, bouncy_base_04.stp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]
2023-07-23 Simplified to use single UART.
2023-07-23 Avoid polling once current state is known
    [code.py]
2023-08-04 Started work with feather 2040
    [Asm3.cfg, BaseCup_brim_01.stp, BaseCup_brim_02.stp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]
2023-08-06 Completed prototype for feather and lipo
    [FrameFor_RP2040_02.3mf, FrameFor_RP2040_03.3mf, FrameFor_RP2040_04.3mf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]
2023-08-12 Case parts for tiny. Code for tiny.
    [CaseFront_0.3mf, CaseFront_1.3mf, CaseFront_2.3mf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]
2023-08-13 CAD for Feather final print. CAD assembly video tiny2040
    [Asm1.cfg, CaseFront_4.3mf, CaseFront_5.3mf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]
